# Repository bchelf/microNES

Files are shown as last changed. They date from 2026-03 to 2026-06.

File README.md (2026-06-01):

# microNES

<p align="center">
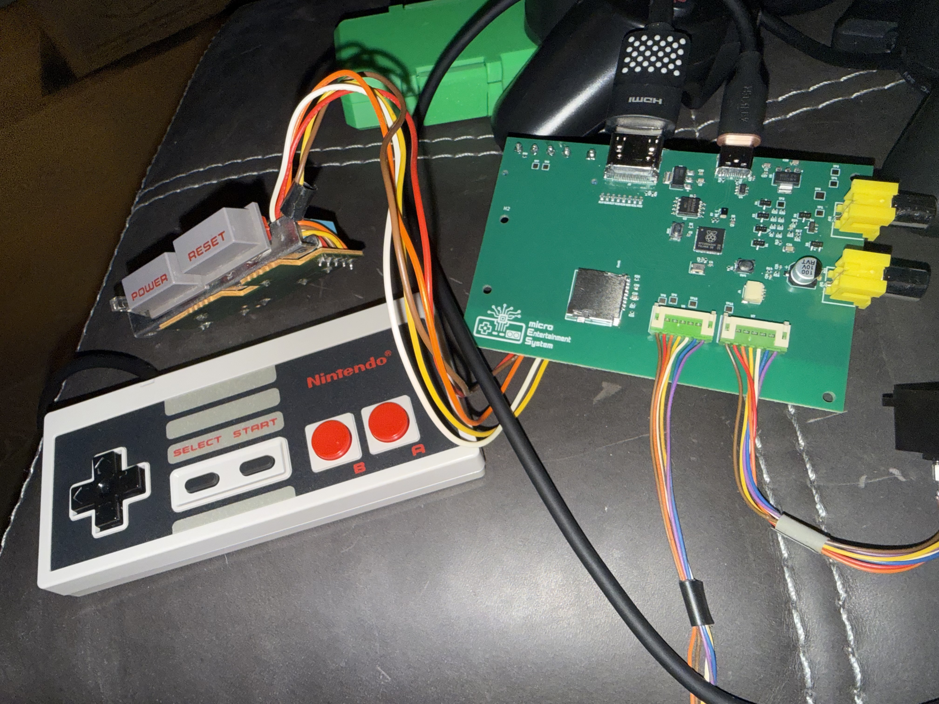
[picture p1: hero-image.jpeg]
microNES RP2350 NES emulator hardware
  
</p>

`microNES` is a small RP2350-based NES emulator project with custom hardware,
portable emulator code, and host-side development tools.

The repo now includes a complete KiCad implementation of an RP2350 console-style
board, plus firmware for composite video, HDMI output, SD-card ROM loading,
controller input, and audio. It also includes host tools for building, running,
capturing, and validating the same emulator core on a desktop.

ROM images are not included.

## What This Repo Does

- Runs NES ROMs through a shared C emulator core.
- Targets RP2350 / Raspberry Pi Pico 2-class hardware.
- Provides a fully functional KiCad PCB design under `hardware/microNES_pcb_v0.1`.
- Outputs analog composite video from the RP2350 using PIO/DMA timing.
- Outputs HDMI/DVI-style video using the RP2350 HSTX path.
- Loads ROMs at runtime from SD card, with an optional flash/XIP cache.
- Supports NES controller input.
- Produces audio through PWM on the Pico targets, with a MAX98357 I2S path for
  the TFT audio target.
- Builds host tools for smoke tests, SDL play, PNG frame dumps, WAV dumps, and
  ffmpeg video capture.
- Includes an ESP32-S3 frontend as a separate reference platform.
- Includes an Emscripten/WebAssembly target stub for browser experiments.

## Current Status

The project has moved beyond the original SMB1-only bring-up. The core still
prioritizes pragmatic compatibility over perfect NES accuracy, but the repo now
contains support for several common mapper families:

- NROM / mapper 0
- MMC1
- UxROM
- CNROM
- AxROM
- GxROM
- Color Dreams
- MMC2
- MMC3
- mapper 40

The hardware and firmware path is centered on the RP2350 board in
`hardware/microNES_pcb_v0.1`, with composite and HDMI firmware targets in
`src/pico`. The host path remains the fastest way to validate emulator behavior
before testing on hardware.

## Hardware

The KiCad project lives here:

```text
hardware/microNES_pcb_v0.1/
```

It includes:

- KiCad schematic and PCB files
- custom symbols and footprints
- RP2350 QFN footprint and 3D model support
- microSD slot support
- USB-C support
- NES controller connector footprint
- custom KiCad footprints for original Nintendo console parts
- composite output hardware
- production outputs, BOM, placement files, and Gerbers

The board is designed around harvested original NES console hardware for the
user-facing controls and controller interface. It uses the original Nintendo
power switch assembly and original NES controller input ports, with custom KiCad
footprints made specifically for those salvaged parts.

The older breadboard composite schematic is documented in `SCHEMATIC.md`. The
PCB target is selected in firmware with:

```sh
-DMICRONES_BOARD=v0_1
```

## Repo Layout

```text
src/common/      Portable emulator core, ROM menu, mappers, CPU, PPU, APU, input
src/host/        Desktop smoke runner, SDL runner, PNG/WAV/video tooling
src/pico/        RP2350 firmware, composite, HDMI, TFT, SD, flash cache, audio
src/esp32s3/     Separate ESP32-S3 frontend/reference implementation
src/web/         Emscripten/WebAssembly browser frontend
hardware/        KiCad PCB design, production files, Gerbers, BOMs
tests/           Emulator test ROMs and menu smoke tests
```

## Build

### Host

```sh
cmake -S . -B build-host -DMICRONES_PLATFORM=host
cmake --build build-host -j
```

This builds:

- `build-host/micrones_smoke`
- `build-host/micrones_menu_smoke`
- `build-host/micrones` when SDL3 is available

Run a ROM locally:

```sh
./build-host/micrones roms/smb1.nes
```

Run deterministic smoke validation:

```sh
./build-host/micrones_smoke roms/smb1.nes
```

Capture a frame or video:

```sh
./build-host/micrones_smoke roms/smb1.nes 6200000 /tmp/micrones_10s.png
./build-host/micrones_smoke roms/smb1.nes --steps 17670500 --video-out build-host/capture.mp4
```

### RP2350 / Pico

Configure the firmware for the emulator and the custom PCB:

```sh
cmake -S . -B build-pico \
  -DMICRONES_PLATFORM=pico \
  -DMICRONES_PICO_VIDEO_MODE=emulator \
  -DMICRONES_BOARD=v0_1 \
  -Dpicotool_DIR=/Users/bchelf/microNES/build/_deps/picotool
```

Build composite output:

```sh
cmake --build build-pico --target micrones_pico_analog -j
```

Build HDMI output:

```sh
cmake --build build-pico --target micrones_pico_hdmi -j
```

Other firmware targets:

```sh
cmake --build build-pico --target micrones_pico_tft -j
cmake --build build-pico --target micrones_pico_tft_max98357 -j
cmake --build build-pico --target micrones_pico_hdmi_test_pattern -j
```

The Pico firmware loads ROMs from SD at runtime. `MICRONES_PICO_ROM_PATH` is no
longer needed for normal Pico builds.

### Web

```sh
emcmake cmake -S . -B build-web -DMICRONES_PLATFORM=web
cmake --build build-web -j
```

The build copies `src/web/index.html` next to the generated JS/WASM output.

### ESP32-S3

```sh
cd src/esp32s3
. $IDF_PATH/export.sh
idf.py build
```

## Host Controls

For the SDL runner:

- Arrow keys or `WASD`: D-pad
- `L`: A
- `K`: B
- `Return`: Start
- `Tab` or right shift: Select

Useful runner options:

```sh
./build-host/micrones roms/smb1.nes --vsync
./build-host/micrones roms/smb1.nes --no-vsync --unthrottled
./build-host/micrones roms/smb1.nes --scale 5
./build-host/micrones roms/smb1.nes --dump-wav /tmp/gameplay.wav --dump-wav-seconds 2
```

## Known Limitations

`microNES` is still an emulator under active development, not a fully accurate
general-purpose NES implementation.

- PPU timing is practical rather than fully cycle-accurate.
- Sprite overflow and exact secondary OAM behavior are incomplete.
- APU fidelity is improved but still not perfect.
- Mapper support exists for several common boards, but compatibility is not
  expected to match mature NES emulators.
- Some RP2350 SD-to-flash-cache ROM load paths can still disturb video output
  and are an active debugging area.

## Development Notes

Keep platform boundaries clean:

- `src/common` should stay portable.
- Host-only SDL, PNG, WAV, and ffmpeg code belongs in `src/host`.
- Pico SDK, PIO, DMA, HSTX, SD, and flash code belongs in `src/pico`.
- ESP-IDF code belongs in `src/esp32s3`.

The recommended workflow is still host-first: validate behavior with
`micrones_smoke` and the SDL runner, then test the same core on RP2350 hardware.

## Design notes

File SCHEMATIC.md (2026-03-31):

# microNES Hardware Schematic

Raspberry Pi Pico 2 (RP2350) running SMB1 with color NTSC composite video output, PWM audio, and a hardware NES controller.

---

## GPIO Pin Assignments

| GPIO | Function | Direction |
|---|---|---|
| GP0  | Video DAC bit 0 (LSB) | Output |
| GP1  | Video DAC bit 1 | Output |
| GP2  | Video DAC bit 2 | Output |
| GP3  | Video DAC bit 3 (MSB) | Output |
| GP4  | Sync clamp MOSFET gate| Output |
| GP5  | NES CLOCK | Output |
| GP6  | NES LATCH | Output |
| GP7  | NES DATA | Input |
| GP9  | Audio PWM | Output |

---

## Composite Video Output

Color NTSC via a 4-bit binary-weighted resistor DAC on GP0–GP3. A MOSFET on GP4 clamps the output to GND during sync pulses for a clean sync tip.

```
GP0 ──[ 1000Ω ]──┐
GP1 ──[  485Ω ]──┤  (470Ω + 15Ω)
GP2 ──[  242Ω ]──┤  (220Ω + 22Ω)
GP3 ──[  120Ω ]──┴── Node A ──[ 75.5Ω series ]── RCA center pin

GP4 ──── MOSFET gate  (N-channel; drain → Node A, source → GND)

RCA shell ──── GND
```

The display provides a 75Ω termination load to ground. The 75.5Ω series resistor plus 75Ω load form a matched output impedance.

**DAC codes (analytically derived at 315 MHz / Node A with 75Ω load):**

| Code | Voltage at RCA | NTSC use |
|---|---|---|
|  0 | 0.000 V | Sync tip (GP4 clamp active) |
|  4 | 0.306 V | Blanking / back porch |
| 13 | 0.998 V | White luma |
| 15 | 1.151 V | Peak chroma headroom  |

Luma range: codes 4–13 (blank to white), scale factor 9 per step.
Chroma: ±2–3 DAC codes added/subtracted on active pixels, 13 hues × 4 subcarrier phases.

---

## Sync Clamp (GP4)

An N-channel MOSFET (e.g. 2N7002 or BSS138) pulls Node A to GND during sync intervals, ensuring the sync tip reaches true 0 V regardless of DAC resistor tolerances.

```
Node A ──── DRAIN
             │
            MOSFET (N-ch)
             │
GP4  ──── GATE
             │
            SOURCE ──── GND
```

GP4 is driven HIGH by the PIO DMA IRQ handler at the start of each sync interval and LOW ~1 µs later by Core 1.

---

## Audio Output

PWM audio on GP9, filtered to remove the 44 kHz carrier before the output jack.

```
GP9 ──[ 1kΩ ]──┬──[ 1kΩ ]──┬── 100µF (DC block) ──┬── audio jack tip
              [10nF]       [10nF]              [10kΩ to GND]
                │             │
               GND           GND
```

- PWM carrier: 44,103 Hz (315 MHz / 7143 — nearest integer to 44,100 Hz, 75 ppm error)
- Two-pole RC low-pass filter: R=1kΩ, C=10nF each pole, f_c ≈ 15.9 kHz
- 100µF DC-blocking cap + 10kΩ bleeder to GND on output
- BAT85 ESD diode pair recommended on the output jack
- Output: mono, line level (passive — may need amplification for speakers)

---

## NES Controller (Pico 2 / RP2350)

Original NES controller connected via its 7-pin cable. The controller contains a 4021 PISO (parallel-in, serial-out) shift register.

```
NES controller cable
  pin 1  VCC   ─── 3.3 V
  pin 2  CLOCK ─── GP5
  pin 3  LATCH ─── GP6
  pin 4  DATA  ─── GP7   (active-low output from controller)
  pin 5  N/C
  pin 6  N/C
  pin 7  GND   ─── GND
```

- DATA is active-low: the controller pulls it low for each pressed button.
- The Pico's internal pull-up on GP7 keeps the line high (no buttons pressed) when no controller is connected.
- No external resistors are needed on CLOCK, LATCH, or DATA.

---

## Full Wiring Summary

```
Pico 2 (RP2350)
┌──────────────────────────────────────────────────────┐
│ GP0 ──[ 1000Ω ]──┐                                   │
│ GP1 ──[  485Ω ]──┤                                   │
│ GP2 ──[  242Ω ]──┤                                   │
│ GP3 ──[  120Ω ]──┴── Node A ──[ 75.5Ω ]── RCA center│   RCA shell ── GND
│ GP4 ─────────────────── MOSFET gate (drain→Node A)   │
│                                                      │
│ GP5 ────────────────────────────────── NES CLOCK     │
│ GP6 ────────────────────────────────── NES LATCH     │
│ GP7 ────────────────────────────────── NES DATA      │
│                                                      │
│ GP9 ──[1kΩ]──[1kΩ]──[100µF]──[10kΩ↓]── audio jack  │
│         │      │                                     │
│        10nF   10nF                                   │
│         │      │                                     │
│ GND ────┴──────┴─────────────────────────────────────┘
│  │
│  └── NES GND, RCA shell, MOSFET source, jack GND
└─────────────────────────────────────────────────────────
```

---

## Notes

- Power the Pico via USB (5V). No additional power supply is needed.
- The Pico runs at exactly 315 MHz (PLL: VCO=1260 MHz, post_div1=2, post_div2=2) with VREG at 1.20V — within RP2350 spec.
- System clock is load-bearing: 315 MHz / 22 = 14.318182 MHz NTSC sample rate (colorburst × 4); 315 MHz / 7143 = 44,103 Hz audio PWM rate.
- All signal ground connections (RCA shell, NES controller, audio jack sleeve, MOSFET source) must share a common GND with the Pico.
- The composite output supports color. Chroma is generated by adding/subtracting DAC codes in sync with the 3.579545 MHz NTSC subcarrier (4 phases × 14.318 MHz ÷ 4).
- The NES controller is also supported on the ESP32-S3 target; see board.h for those pin assignments (GPIO 11/12/13).

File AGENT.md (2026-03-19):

# micrones Agent Notes

This file summarizes the current state of `micrones`, what has already been implemented and validated, what has been learned during debugging, and what remains.

## Project Intent

`micrones` is intentionally narrow:

- It is not a general NES emulator.
- It targets the original Super Mario Bros ROM.
- It only supports mapper 0 / NROM.
- It is being developed as a shared portable NES runtime plus thin host and Pico frontends.
- The long-term embedded target is RP2350 / Raspberry Pi Pico 2.

The current architecture is:

- `src/common/`
  - Portable shared emulator/runtime code.
  - No SDL, no Pico SDK, no host-only image/audio/window code.
- `src/host/`
  - Host-only tooling:
  - smoke validation runner
  - PNG export
  - ffmpeg video capture
  - SDL interactive runner
  - SDL audio playback
- `src/pico/`
  - Pico firmware and hardware-specific code.

## What Is Working

### Build / Targets

- Host smoke target builds and runs:
  - `build-host/micrones_smoke`
- Host SDL interactive runner builds and runs:
  - `build-host/micrones_run`
- Pico firmware builds and produces:
  - `build-pico/micrones.uf2`
  - `build-pico/micrones.elf`

### Core Emulator

- iNES ROM parsing works.
- Mapper 0 / NROM-only support works.
- CPU execution is deterministic for SMB1.
- Missing official CPU opcodes needed by SMB1 have already been implemented.
- No illegal opcodes have been required by SMB1 so far.
- Deterministic host validation has repeatedly passed.

### PPU / Video

- Background rendering exists and produces a visible `256x240` framebuffer.
- Minimal sprite composition exists.
- Sprite 0 hit is implemented from real OAM/background overlap.
- SMB1 gets past the early and later sprite-0-hit wait loops.
- The later sprite-0-hit failure was traced to background address derivation and fixed with a more honest latched `v/t/x/w`-style model.
- A later visual split bug near the HUD/title-card boundary was traced to deferred whole-scanline rendering using stale scanline-start scroll state when SMB updated `PPUSCROLL` on visible scanline 32.
- That split bug was fixed by refreshing the deferred scanline render latch when visible writes hit scroll-affecting PPU registers.

### Host Tooling

- PNG export works from the host runner.
- ffmpeg video capture works by piping raw grayscale frames into ffmpeg.
- SDL interactive window works.
- Keyboard input mapping works for SMB1 gameplay.
- Host-side approximate color mapping exists for SDL display.
- Host-side frame pacing infrastructure exists.

### Audio

- Shared-core PCM sample pipeline exists in `src/common`.
- Host-side SDL audio playback works.
- SMB1 audio is audible and recognizable.
- Audio is still incomplete and simplified.

## Current Architecture Details

### Shared Core

Key portable areas include:

- CPU
- PPU
- APU
- cartridge/NROM
- input/controller state
- framebuffer and scanline types
- frame pacing abstraction

Important design rule:

- Keep emulator logic portable.
- Do not add host-only or Pico-only dependencies to `src/common/`.

### Host Side

Current host capabilities:

- smoke validation with deterministic reporting
- frame hashing and state hashing
- sprite-0 diagnostics
- PNG export
- ffmpeg video capture
- SDL interactive window
- SDL keyboard controller input
- SDL audio playback

### Pico Side

Current Pico scope:

- buildable firmware
- earlier composite bring-up code still exists
- Pico-specific timing shim exists for future shared pacing integration

Do not assume the Pico runtime is yet using the full host-side emulator/display/audio path.

## Important Findings So Far

### 1. SMB1 CPU Execution Was Not the Main Blocker

Earlier debugging showed SMB1 could run millions of instructions deterministically. Once the missing official opcodes needed by SMB1 were implemented, the next blockers were PPU-side, not CPU decode.

### 2. The First Major Gameplay Stall Was Sprite-0-Hit Related

SMB1 stalled in the loop at:

- `LDA $2002`
- `AND #$40`
- `BEQ ...`

This was because `PPUSTATUS` bit 6 was never being raised. The minimal viable sprite-0-hit path fixed that.

### 3. The Later Gameplay Stall Was Also Not a Sprite-OAM Problem

Forensic work showed that later in gameplay:

- sprite 0 OAM remained plausible
- sprite 0 still had nonzero pixels
- sprite 0 still appeared in first-8 scanline selection
- the actual failure was that background under sprite 0 became transparent in the current model

This pointed to background/scroll/address derivation, not sprite corruption.

### 4. A More Honest Latched Scroll/Address Model Was Required

The simplified global scroll model was not enough. Moving to a more honest `PPUCTRL` / `PPUSCROLL` / `PPUADDR`-driven latched address model was required to keep later sprite-0 hit behavior working.

### 5. The HUD / Title-Card Visual Artifact Was a Same-Scanline Split Bug

The artifact became visually obvious around 8-10 seconds into gameplay.

Observed symptom:

- a line at the top of the title card persisted instead of scrolling with the card
- this was visible in PNG/video captures, so not an SDL presentation issue

What we learned:

- the bad row was scanline `32`
- SMB writes `PPUSCROLL` during visible scanline `32`
- the renderer defers whole-scanline drawing until end-of-line
- the scanline renderer had been using stale line-start render state for that row

Minimal fix:

- when visible writes hit `PPUCTRL`, `PPUSCROLL`, or `PPUADDR`, refresh the deferred scanline render latch for that same line

This preserved the scanline-based renderer without a broad PPU rewrite.

## Determinism / Validation Status

Validated repeatedly:

- host smoke determinism passes
- frame hashes are stable under repeat runs
- sprite-0 hit behavior is deterministic
- host and Pico builds both succeed after recent changes

Useful smoke commands:

```sh
cd /Users/bchelf/microNES
cmake --build build-host -j
./build-host/micrones_smoke roms/smb1.nes
```

Frame dump examples:

```sh
./build-host/micrones_smoke roms/smb1.nes 5000000 /tmp/micrones_8s.png
./build-host/micrones_smoke roms/smb1.nes 6200000 /tmp/micrones_10s.png
```

Video capture example:

```sh
./build-host/micrones_smoke roms/smb1.nes --steps 17670500 --video-out build-host/smb_30s.mp4
```

SDL runner:

```sh
./build-host/micrones_run roms/smb1.nes
```

## Current Audio Status

Audio is working end-to-end, but it is still incomplete.

What is true right now:

- audible SMB1 audio exists
- it is recognizable and in sync
- it is not badly delayed or grossly distorted

Known limitations:

- bass is still weaker than it should be
- some sound effects still sound abbreviated or clipped at the tail
- APU behavior is still approximate
- noise/DMC/precise envelope/frame-counter behavior are not yet complete enough for faithful SMB audio

Conclusion:

- the SDL host audio backend is probably not the main problem now
- the remaining work is primarily in `src/common/apu.*`

## Current Rendering Status

What works:

- background rendering is solid enough for SMB1 progression and inspection
- sprite composition is present and sufficient for recognizable gameplay
- sprite-0 hit works in early and later gameplay
- the major late split bug at the HUD/title-card boundary has been fixed narrowly

What is still simplified:

- no cycle-accurate PPU fetch pipeline
- no exact secondary OAM behavior
- no sprite overflow behavior
- no full palette-accurate NES color in the core
- host color display is still an approximation layered on top of the debug-oriented framebuffer

## Current Host SDL Status

Interactive runner status:

- window rendering works
- keyboard input works
- gameplay works
- grayscale upload bug was fixed by using the correct SDL pixel format for byte-wise RGBA data
- approximate host-only color mapping exists
- frame pacing exists but can still look choppy or tear depending on mode

Likely causes of choppiness/tearing already identified:

- pacer-driven presentation with vsync disabled
- host scheduling jitter
- refresh mismatch between NES cadence and actual display

Practical modes:

- live play: prefer `--vsync`
- benchmarking/perf: prefer `--no-vsync --unthrottled`

## What Remains

### APU

Highest-value remaining audio work:

- improve frame sequencer timing
- improve envelope behavior
- improve length counter behavior
- improve triangle sustain / presence
- improve pulse/noise completeness

### PPU

Still intentionally incomplete:

- no full cycle-accurate PPU
- no exact per-dot reload/fetch behavior
- no sprite overflow emulation
- no exact secondary OAM behavior
- no exact final NES palette behavior in the core

### Pico Runtime Integration

Still to do later:

- connect the shared emulator core to a Pico-ready video path
- connect the shared PCM sample pipeline to a Pico audio backend
- integrate the shared frame pacer into the eventual Pico runtime loop
- performance work for RP2350

### General Project Direction

The next work should stay disciplined:

- avoid broad emulator-generalization
- continue prioritizing SMB1-specific correctness
- keep portability boundaries intact

## Guidelines for Future Changes

- Prefer narrow fixes over broad rewrites.
- Do not add host-only code to `src/common/`.
- Do not add Pico SDK dependencies to the shared core.
- Keep deterministic smoke validation healthy after every meaningful renderer/APU change.
- When debugging rendering:
  - capture PNGs/videos from host tooling
  - compare frame windows numerically when possible
  - instrument exact PPU register writes before assuming generic tile-fetch corruption
- When debugging gameplay stalls:
  - first determine whether CPU, PPU, NMI, frame hashes, and sprite-0 hit are still advancing
  - do not guess broadly without evidence

## Current Repo-Specific Commands

Build host:

```sh
cd /Users/bchelf/microNES
cmake -S . -B build-host -DMICRONES_PLATFORM=host
cmake --build build-host -j
```

Build Pico:

```sh
cd /Users/bchelf/microNES
source ~/.zshrc
cmake -S . -B build-pico -DMICRONES_PLATFORM=pico -Dpicotool_DIR=/Users/bchelf/microNES/build/_deps/picotool
cmake --build build-pico -j
```

Run SDL:

```sh
./build-host/micrones_run roms/smb1.nes
```

Run smoke:

```sh
./build-host/micrones_smoke roms/smb1.nes
```

## Current Bottom Line

`micrones` now has:

- a serious shared SMB1/NROM runtime
- deterministic host validation
- working framebuffer generation
- working sprite-0 hit
- working host PNG/video capture
- working host SDL interaction
- working first-pass audio pipeline

The main remaining technical debt is:

- APU completeness
- deeper PPU accuracy where SMB later requires it
- eventual Pico-side integration/performance work

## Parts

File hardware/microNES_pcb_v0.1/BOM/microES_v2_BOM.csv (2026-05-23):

Comment | Designator | Footprint | JLCPCB Part #
AV-5 | AV1,AV2 | microNES_footprints:CONN-TH_AV-5 | C18080
10uF | C1,C5,C19,C26,C29 | Capacitor_SMD:C_0603_1608Metric | C19702
100nF | C2,C8,C11,C12,C13,C14,C15,C16,C17,C18,C20,C27,C28,C30 | Capacitor_SMD:C_0402_1005Metric | C307331
15pF | C3,C4 | Capacitor_SMD:C_0402_1005Metric | C1548
4.7uF | C6,C7,C9,C10 | Capacitor_SMD:C_0402_1005Metric | C23733
100nF | C21 | Capacitor_SMD:C_0805_2012Metric | C49678
10nF | C22,C24,C25 | Capacitor_SMD:C_0402_1005Metric | C15195
100uF | C23 | Capacitor_SMD:CP_Elec_6.3x5.4 | C29179
TF PUSH | Card1 | microNES_footprints:TF-SMD_TF-PUSH | C393941
BAT54S | D1,D2,D3,D4,D5,D6 | Package_TO_SOT_SMD:SOT-23 | C47546
USB_C_Receptacle_USB2.0_16P | J1 | microNES_footprints:USB-C_SMD-TYPE-C-31-M-12_1 | C165948
HDMI_E | J3 | Connector_Video:HDMI_A_Molex_208658-1001_Horizontal | C2962407
SM03B-SRSS-TB | J4 | Connector_JST:JST_SH_SM03B-SRSS-TB_1x03-1MP_P1.00mm_Horizontal | C160403
3.3uH | L1 | microNES_footprints:IND-SMD_L2.0-W1.6_AOTA-B201610S3R3-101-T | C42411119
2N7002 | Q1 | Package_TO_SOT_SMD:SOT-23 | C8545
1k | R2,R3,R4,R6,R14,R16 | Resistor_SMD:R_0402_1005Metric | C11702
33 | R5 | Resistor_SMD:R_0402_1005Metric | C25105
27 | R7,R8 | Resistor_SMD:R_0402_1005Metric | C25100
270 | R10,R26,R27,R28,R29,R30,R31,R32 | Resistor_SMD:R_0603_1608Metric | C22966
5.1k | R11,R12 | Resistor_SMD:R_0402_1005Metric | C25905
330 | R13,R40 | Resistor_SMD:R_0402_1005Metric | C25104
10k | R15,R21,R33,R35,R36,R37 | Resistor_SMD:R_0402_1005Metric | C2765610
7.5 | R17 | Resistor_SMD:R_0402_1005Metric | C47764
68 | R18 | Resistor_SMD:R_0402_1005Metric | C25131
15 | R19 | Resistor_SMD:R_0402_1005Metric | C25083
470 | R20 | Resistor_SMD:R_0402_1005Metric | C25117
22 | R22 | Resistor_SMD:R_0402_1005Metric | C25092
220 | R23 | Resistor_SMD:R_0402_1005Metric | C25091
100 | R24 | Resistor_SMD:R_0402_1005Metric | C2784782
120 | R25 | Resistor_SMD:R_0402_1005Metric | C25079
20k | R34 | Resistor_SMD:R_0402_1005Metric | C25765
0 | R38,R39 | Resistor_SMD:R_0402_1005Metric | C17168
PTS810SJM250SMTRLFS | SW3,SW4 | microNES_footprints:KEY-SMD_4P-L4.2-W3.2-P2.20-LS4.6 | C116501
RP2350_60QFN | U1 | microNES_footprints:RP2350-QFN-60-1EP_7x7_P0.4mm_EP3.4x3.4mm_ThermalVias | C42411118
AMS1117-3.3 | U2,U5 | Package_TO_SOT_SMD:SOT-223-3_TabPin2 | C6186
W25Q128JVS | U3 | Package_SO:SOIC-8_5.3x5.3mm_P1.27mm | C97521
 | U4 | Package_TO_SOT_SMD:SOT-23-6 | C7519
ABM8-272-T3 | Y1 | Crystal:Crystal_SMD_3225-4Pin_3.2x2.5mm | C20625731

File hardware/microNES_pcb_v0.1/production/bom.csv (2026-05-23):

Designator | Footprint | Quantity | Value | LCSC Part #
AV1, AV2 | CONN-TH_AV-5 | 2 | AV-5 | C18080
C1 | 0603 | 1 | 10uF
C10, C6, C7, C9 | 0402 | 4 | 4.7uF | C23733
C11, C12, C13, C14, C15, C16, C17, C18, C2, C20, C27, C28, C30, C8 | 0402 | 14 | 100nF | C307331
C19, C26, C29, C5 | 0603 | 4 | 10uF | C19702
C21 | 0805 | 1 | 100nF | C49678
C22, C24, C25 | 0402 | 3 | 10nF | C15195
C23 | CP_Elec_6.3x5.4 | 1 | 100uF | C29179
C3, C4 | 0402 | 2 | 15pF | C1548
CARD1 | TF-SMD_TF-PUSH | 1 | TF PUSH | C393941
D1, D2, D3, D4, D5, D6 | SOT-23 | 6 | BAT54S | C47546
H1, H2, H3, H4 | MountingHole_2.7mm_M2.5 | 4 | MountingHole
J1 | USB-C_SMD-TYPE-C-31-M-12_1 | 1 | USB_C_Receptacle_USB2.0_16P | C165948
J3 | HDMI_A_Molex_208658-1001_Horizontal | 1 | HDMI_E | C2962407
J4 | JST_SH_SM03B-SRSS-TB_1x03-1MP_P1.00mm_Horizontal | 1 | SM03B-SRSS-TB | C160403
L1 | IND-SMD_L2.0-W1.6_AOTA-B201610S3R3-101-T | 1 | 3.3uH | C42411119
Q1 | SOT-23 | 1 | 2N7002 | C8545
R10, R26, R27, R28, R29, R30, R31, R32 | 0603 | 8 | 270 | C22966
R11, R12 | 0402 | 2 | 5.1k | C25905
R13, R40 | 0402 | 2 | 330 | C25104
R14, R16, R3 | 0402 | 3 | 1k | C2784783
R15, R21, R33, R35, R36, R37 | 0402 | 6 | 10k | C2765610
R17 | 0402 | 1 | 7.5 | C47764
R18 | 0402 | 1 | 68 | C25131
R19 | 0402 | 1 | 15 | C25083
R2, R4, R6 | 0402 | 3 | 1k | C11702
R20 | 0402 | 1 | 470 | C25117
R22 | 0402 | 1 | 22 | C25092
R23 | 0402 | 1 | 220 | C25091
R24 | 0402 | 1 | 100 | C2784782
R25 | 0402 | 1 | 120 | C25079
R34 | 0402 | 1 | 20k | C25765
R38, R39 | 0402 | 2 | 0 | C17168
R5 | 0402 | 1 | 33 | C25105
R7 | 0402 | 1 | 27 | C25100
R8 | 0402 | 1 | 27 | C25100
SW3, SW4 | KEY-SMD_4P-L4.2-W3.2-P2.20-LS4.6 | 2 | PTS810SJM250SMTRLFS | C116501
TP1 | TestPoint_Pad_1.5x1.5mm | 1 | TestPoint
TP10, TP11, TP2, TP3, TP4, TP6, TP7, TP8, TP9 | TestPoint_Pad_1.5x1.5mm | 9 | ~
TP5 | TestPoint_Pad_2.0x2.0mm | 1 | TestPoint
U1 | RP2350-QFN-60-1EP_7x7_P0.4mm_EP3.4x3.4mm_ThermalVias | 1 | RP2350_60QFN | C42411118
U2, U5 | SOT-223-3_TabPin2 | 2 | AMS1117-3.3 | C6186
U3 | SOIC-8_5.3x5.3mm_P1.27mm | 1 | W25Q128JVS | C97521
U4 | SOT-23-6 | 1 | ~ | C7519
U6, U7 | NES_1x7_CustomPitch | 2 | ~
U8 | NES_Power_Reset_LED_5pin | 1 | ~
Y1 | Crystal_SMD_3225-4Pin_3.2x2.5mm | 1 | ABM8-272-T3 | C20625731

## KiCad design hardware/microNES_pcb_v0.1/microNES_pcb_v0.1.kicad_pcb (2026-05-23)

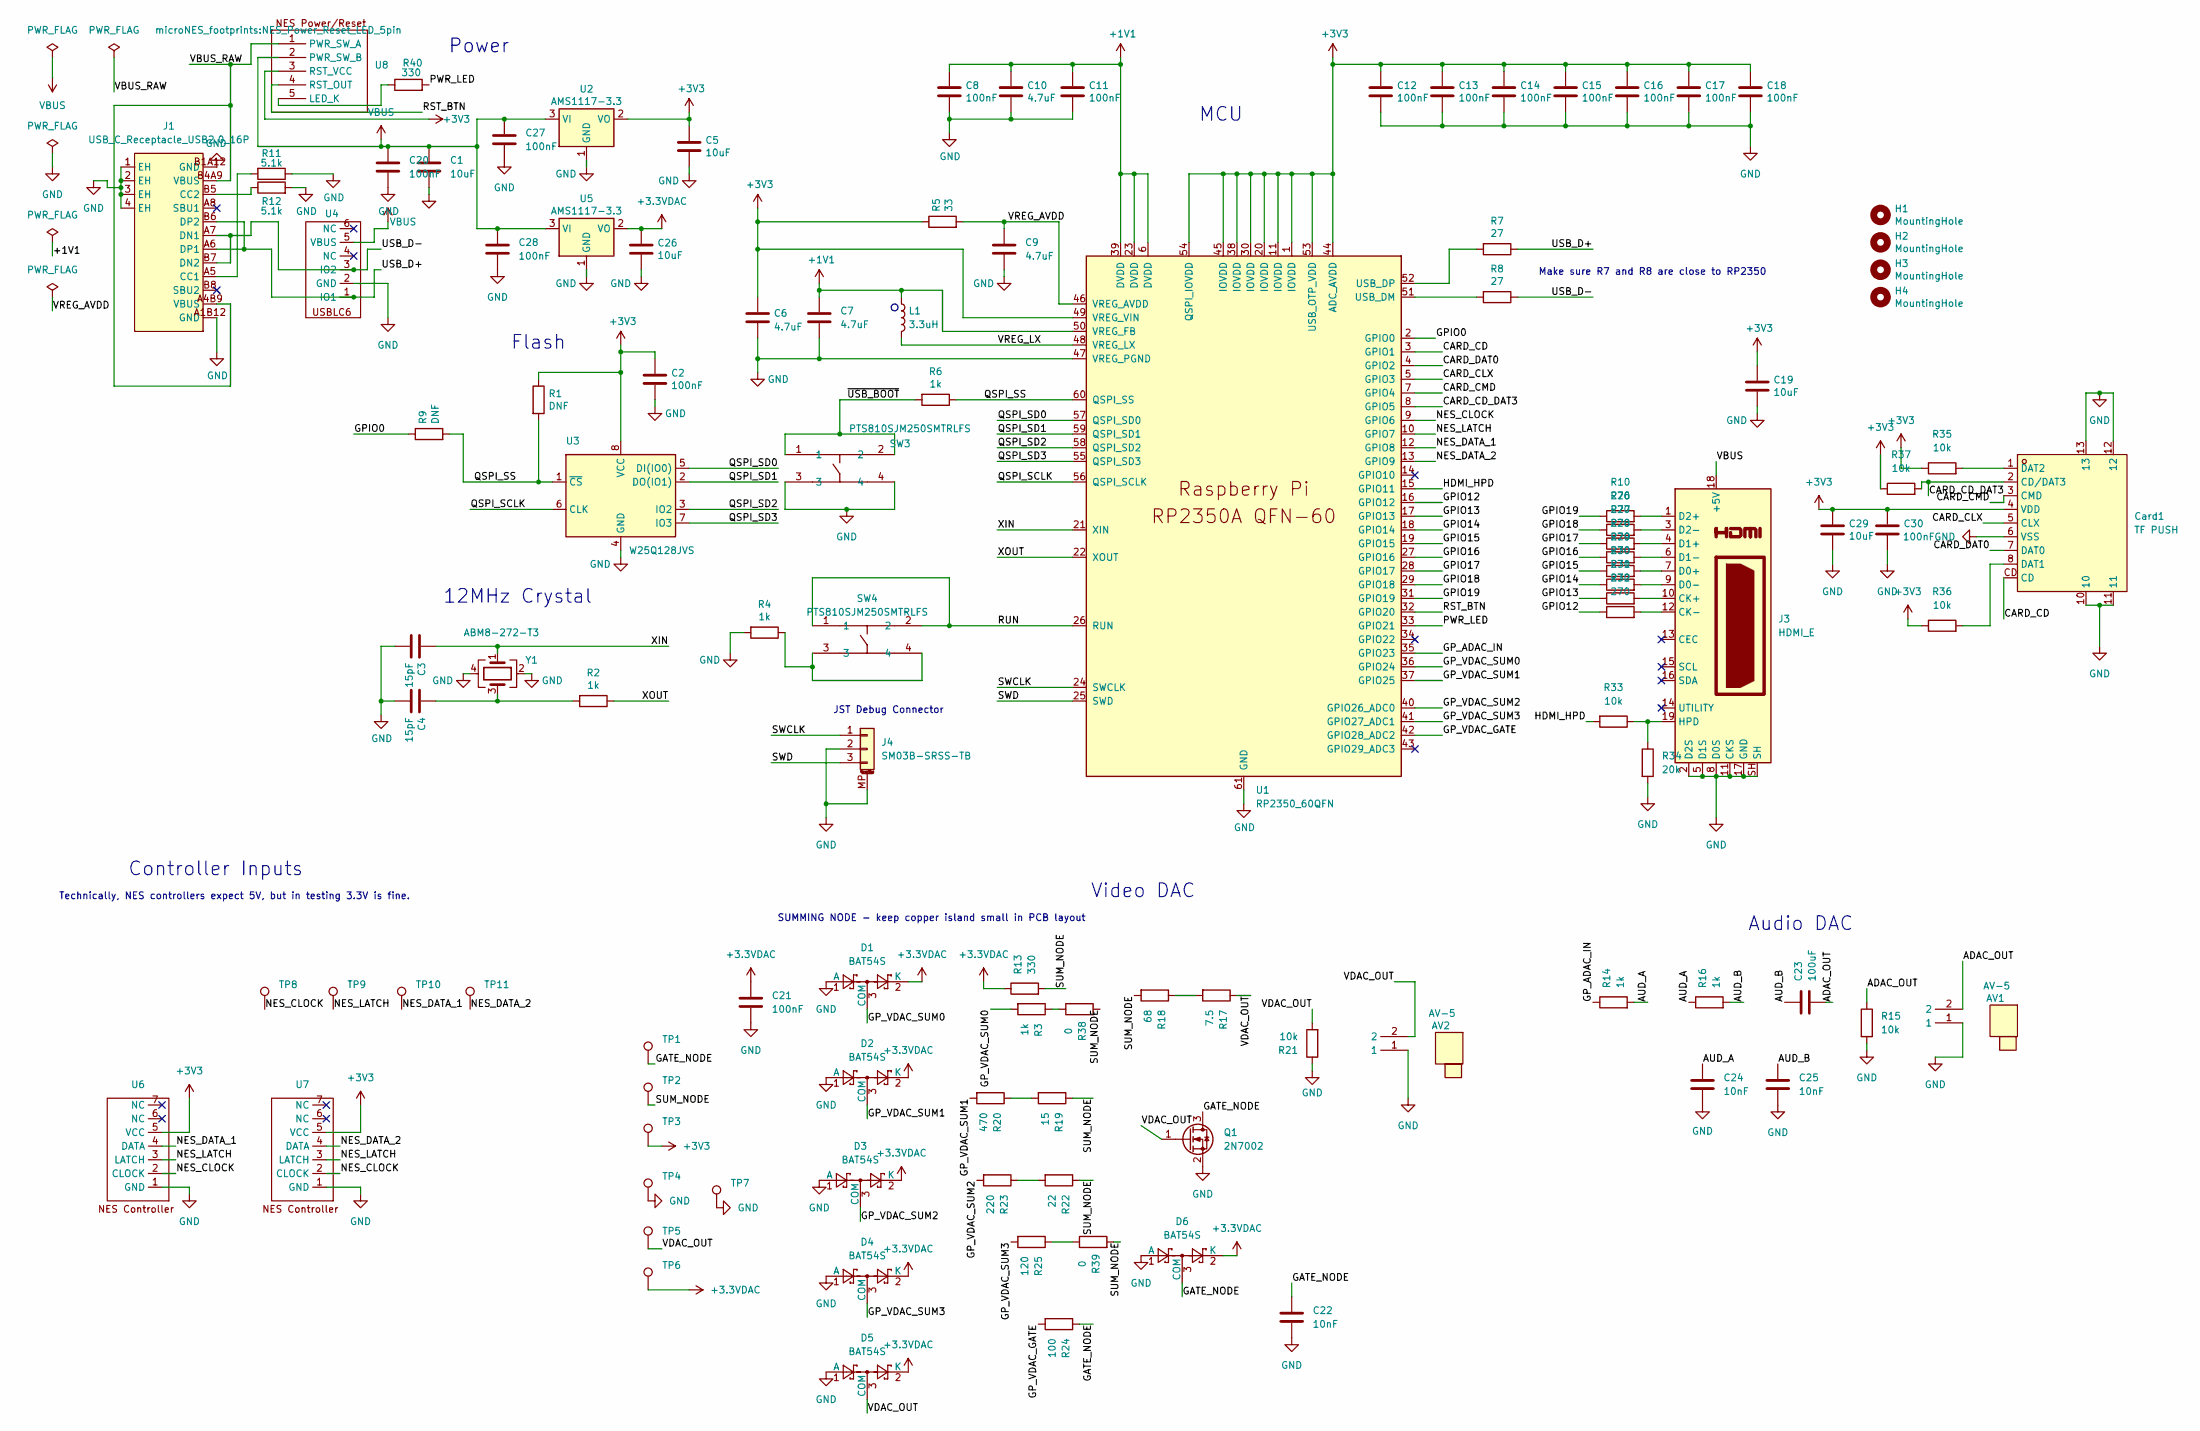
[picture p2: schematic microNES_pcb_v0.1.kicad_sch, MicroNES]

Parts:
AV1: AV-5; CONN-TH_AV-5; MPN AV-5; LCSC C18080
AV2: AV-5; CONN-TH_AV-5; MPN AV-5; LCSC Part C18080
C1: 10uF; C_0603_1608Metric
C2, C8, C11, C12, C13, C14, C15, C16, C17, C18, C20, C27, C28, C30: 100nF; C_0402_1005Metric; LCSC C307331
C3, C4: 15pF; C_0402_1005Metric; LCSC C1548
C5, C19, C26, C29: 10uF; C_0603_1608Metric; LCSC C19702
C6, C7, C9, C10: 4.7uF; C_0402_1005Metric; LCSC C23733
C21: 100nF; C_0805_2012Metric; LCSC C49678
C22, C24, C25: 10nF; C_0402_1005Metric; LCSC C15195
C23: 100uF; CP_Elec_6.3x5.4; LCSC C29179
Card1: TF PUSH; TF-SMD_TF-PUSH; MPN TF PUSH; LCSC C393941
D1, D2, D3, D4, D5, D6: BAT54S; SOT-23; LCSC C47546
H1, H2, H3, H4: MountingHole; MountingHole_2.7mm_M2.5
J1: USB_C_Receptacle_USB2.0_16P; USB-C_SMD-TYPE-C-31-M-12_1; LCSC C165948
J3: HDMI_E; HDMI_A_Molex_208658-1001_Horizontal; LCSC C2962407
J4: SM03B-SRSS-TB; JST_SH_SM03B-SRSS-TB_1x03-1MP_P1.00mm_Horizontal; LCSC C160403
L1: 3.3uH; IND-SMD_L2.0-W1.6_AOTA-B201610S3R3-101-T; LCSC C42411119
Q1: 2N7002; SOT-23; LCSC C8545
R1, R9: DNF; R_0402_1005Metric
R2, R4, R6: 1k; R_0402_1005Metric; LCSC C11702
R3, R14, R16: 1k; R_0402_1005Metric; LCSC C2784783
R5: 33; R_0402_1005Metric; LCSC C25105
R7, R8: 27; R_0402_1005Metric; LCSC C25100
R10, R26, R27, R28, R29, R30, R31, R32: 270; R_0603_1608Metric; LCSC C22966
R11, R12: 5.1k; R_0402_1005Metric; LCSC C25905
R13, R40: 330; R_0402_1005Metric; LCSC C25104
R15, R21, R33, R35, R36, R37: 10k; R_0402_1005Metric; LCSC C2765610
R17: 7.5; R_0402_1005Metric; LCSC C47764
R18: 68; R_0402_1005Metric; LCSC C25131
R19: 15; R_0402_1005Metric; LCSC C25083
R20: 470; R_0402_1005Metric; LCSC C25117
R22: 22; R_0402_1005Metric; LCSC C25092
R23: 220; R_0402_1005Metric; LCSC C25091
R24: 100; R_0402_1005Metric; LCSC C25076
R25: 120; R_0402_1005Metric; LCSC C25079
R34: 20k; R_0402_1005Metric; LCSC C25765
R38, R39: 0; R_0402_1005Metric; LCSC C17168
SW3: PTS810SJM250SMTRLFS; KEY-SMD_4P-L4.2-W3.2-P2.20-LS4.6; MPN PTS810SJM250SMTRLFS; LCSC C116501
SW4: PTS810SJM250SMTRLFS; KEY-SMD_4P-L4.2-W3.2-P2.20-LS4.6; MPN PTS810SJM250SMTRLFS; LCSC Part C116501
TP1: TestPoint; TestPoint_Pad_1.5x1.5mm
TP2, TP3, TP4, TP6, TP7, TP8, TP9, TP10, TP11: TestPoint_Pad_1.5x1.5mm
TP5: TestPoint; TestPoint_Pad_2.0x2.0mm
U1: RP2350_60QFN; RP2350-QFN-60-1EP_7x7_P0.4mm_EP3.4x3.4mm_ThermalVias; LCSC C42411118
U2, U5: AMS1117-3.3; SOT-223-3_TabPin2; LCSC C6186
U3: W25Q128JVS; SOIC-8_5.3x5.3mm_P1.27mm; LCSC C97521
U4: SOT-23-6; LCSC C7519
U6, U7: NES_1x7_CustomPitch
U8: NES_Power_Reset_LED_5pin
Y1: ABM8-272-T3; Crystal_SMD_3225-4Pin_3.2x2.5mm; LCSC C20625731

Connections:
+1V1: C7.1, C8.1, C10.1, C11.1, L1.1, U1.6 (DVDD), U1.23 (DVDD), U1.39 (DVDD), U1.50 (VREG_FB)
+3.3VDAC: C21.1, C26.1, D1.2 (K), D2.2 (K), D3.2 (K), D4.2 (K), D5.2 (K), D6.2 (K), R13.1, TP6.1 (1_1), U5.2 (VO)
+3V3: C2.1, C5.1, C6.1, C12.1, C13.1, C14.1, C15.1, C16.1, C17.1, C18.1, C19.1, C29.1, C30.1, Card1.4 (VDD), R1.1, R5.1, R35.1, R36.1, R37.1, TP3.1 (1_1), U1.1 (IOVDD), U1.11 (IOVDD), U1.20 (IOVDD), U1.30 (IOVDD), U1.38 (IOVDD), U1.44 (ADC_AVDD), U1.45 (IOVDD), U1.49 (VREG_VIN), U1.53 (USB_OTP_VDD), U1.54 (QSPI_IOVDD), U2.2 (VO), U3.8 (VCC), U6.5 (VCC), U7.5 (VCC), U8.3 (RST_VCC)
/ADAC_OUT: AV1.2, C23.2, R15.1
/AUD_A: C24.1, R14.2, R16.1
/AUD_B: C23.1, C25.1, R16.2
/CARD_CD: Card1.CD, U1.3 (GPIO1)
/CARD_CD_DAT3: Card1.2 (CD/DAT3), R37.2, U1.8 (GPIO5)
/CARD_CLX: Card1.5 (CLX), U1.5 (GPIO3)
/CARD_CMD: Card1.3 (CMD), U1.7 (GPIO4)
/CARD_DAT0: Card1.7 (DAT0), U1.4 (GPIO2)
/GATE_NODE: C22.1, D6.3 (COM), Q1.3 (D), R24.1, TP1.1 (1_1)
/GPIO0: R9.1, U1.2 (GPIO0)
/GPIO12: R32.1, U1.16 (GPIO12)
/GPIO13: R31.1, U1.17 (GPIO13)
/GPIO14: R30.1, U1.18 (GPIO14)
/GPIO15: R29.1, U1.19 (GPIO15)
/GPIO16: R28.1, U1.27 (GPIO16)
/GPIO17: R27.1, U1.28 (GPIO17)
/GPIO18: R26.1, U1.29 (GPIO18)
/GPIO19: R10.1, U1.31 (GPIO19)
/GP_ADAC_IN: R14.1, U1.35 (GPIO23)
/GP_VDAC_GATE: R24.2, U1.42 (GPIO28_ADC2)
/GP_VDAC_SUM0: D1.3 (COM), R3.2, U1.36 (GPIO24)
/GP_VDAC_SUM1: D2.3 (COM), R20.2, U1.37 (GPIO25)
/GP_VDAC_SUM2: D3.3 (COM), R23.2, U1.40 (GPIO26_ADC0)
/GP_VDAC_SUM3: D4.3 (COM), R25.2, U1.41 (GPIO27_ADC1)
/HDMI_HPD: R33.2, U1.15 (GPIO11)
/NES_CLOCK: TP8.1 (1_1), U1.9 (GPIO6), U6.2 (CLOCK), U7.2 (CLOCK)
/NES_DATA_1: TP10.1 (1_1), U1.12 (GPIO8), U6.4 (DATA)
/NES_DATA_2: TP11.1 (1_1), U1.13 (GPIO9), U7.4 (DATA)
/NES_LATCH: TP9.1 (1_1), U1.10 (GPIO7), U6.3 (LATCH), U7.3 (LATCH)
/PWR_LED: R40.2, U1.33 (GPIO21)
/QSPI_SCLK: U1.56 (QSPI_SCLK), U3.6 (CLK)
/QSPI_SD0: U1.57 (QSPI_SD0), U3.5 (DI(IO0))
/QSPI_SD1: U1.59 (QSPI_SD1), U3.2 (DO(IO1))
/QSPI_SD2: U1.58 (QSPI_SD2), U3.3 (IO2)
/QSPI_SD3: U1.55 (QSPI_SD3), U3.7 (IO3)
/QSPI_SS: R1.2, R6.1, R9.2, U1.60 (QSPI_SS), U3.1 (~CS)
/RST_BTN: U1.32 (GPIO20), U8.4 (RST_OUT)
/RUN: SW4.1, SW4.2, U1.26 (RUN)
/SUM_NODE: R13.2, R18.2, R19.1, R22.1, R38.2, R39.2, TP2.1 (1_1)
/SWCLK: J4.1, U1.24 (SWCLK)
/SWD: J4.3, U1.25 (SWD)
/USB_D+: J1.A6 (DP1), J1.B6 (DP2), R7.1, U4.1 (IO1)
/USB_D-: J1.A7 (DN1), J1.B7 (DN2), R8.1, U4.3 (IO2)
/VBUS_RAW: J1.A4B9 (VBUS), J1.B4A9 (VBUS), U8.1 (PWR_SW_A)
/VDAC_OUT: AV2.2, D5.3 (COM), Q1.1 (G), R17.1, R21.2, TP5.1 (1_1)
/VREG_AVDD: C9.1, R5.2, U1.46 (VREG_AVDD)
/VREG_LX: L1.2, U1.48 (VREG_LX)
/XIN: C3.1, U1.21 (XIN), Y1.1
/XOUT: R2.1, U1.22 (XOUT)
/~USB_BOOT: R6.2, SW3.1, SW3.2
GND: AV1.1, AV2.1, C1.1, C2.2, C3.2, C4.2, C5.2, C6.2, C7.2, C8.2, C9.2, C10.2, C11.2, C12.2, C13.2, C14.2, C15.2, C16.2, C17.2, C18.2, C19.2, C20.1, C21.2, C22.2, C24.2, C25.2, C26.2, C27.1, C28.1, C29.2, C30.2, Card1.6 (VSS), Card1.10, Card1.11, Card1.12, Card1.13, D1.1 (A), D2.1 (A), D3.1 (A), D4.1 (A), D5.1 (A), D6.1 (A), J1.1 (EH), J1.2 (EH), J1.3 (EH), J1.4 (EH), J1.A1B12 (GND), J1.B1A12 (GND), J3.2 (D2S), J3.5 (D1S), J3.8 (D0S), J3.11 (CKS), J3.17 (GND), J3.SH, J4.2, J4.MP (MountPin), Q1.2 (S), R4.2, R11.1, R12.2, R15.2, R21.1, R34.2, SW3.3, SW3.4, TP4.1 (1_1), TP7.1 (1_1), U1.47 (VREG_PGND), U1.61 (GND), U2.1 (GND), U3.4 (GND), U4.2 (GND), U5.1 (GND), U6.1 (GND), U7.1 (GND), Y1.2, Y1.4
unnamed: C4.1, R2.2, Y1.3
unnamed: Card1.8 (DAT1), R36.2
unnamed: Card1.1 (DAT2), R35.2
unnamed: J1.A5 (CC1), R11.2
unnamed: J1.B5 (CC2), R12.1
unnamed: J3.10 (CK+), R31.2
unnamed: J3.12 (CK-), R32.2
unnamed: J3.7 (D0+), R29.2
unnamed: J3.9 (D0-), R30.2
unnamed: J3.4 (D1+), R27.2
unnamed: J3.6 (D1-), R28.2
unnamed: J3.1 (D2+), R10.2
unnamed: J3.3 (D2-), R26.2
unnamed: J3.19 (HPD), R33.1, R34.1
unnamed: R3.1, R38.1
unnamed: R4.1, SW4.3, SW4.4
unnamed: R17.2, R18.1
unnamed: R19.2, R20.1
unnamed: R22.2, R23.1
unnamed: R25.1, R39.1
unnamed: R8.2, U1.51 (USB_DM)
unnamed: R7.2, U1.52 (USB_DP)
unnamed: R40.1, U8.5 (LED_K)
VBUS: C1.2, C20.2, C27.2, C28.2, J3.18 (+5V), U2.3 (VI), U4.5 (VBUS), U5.3 (VI), U8.2 (PWR_SW_B)

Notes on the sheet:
Technically, NES controllers expect 5V, but in testing 3.3V is fine.
Flash
MCU
Video DAC
Controller Inputs
12MHz Crystal
Make sure R7 and R8 are close to RP2350
JST Debug Connector
Audio DAC
SUMMING NODE - keep copper island small in PCB layout
Power

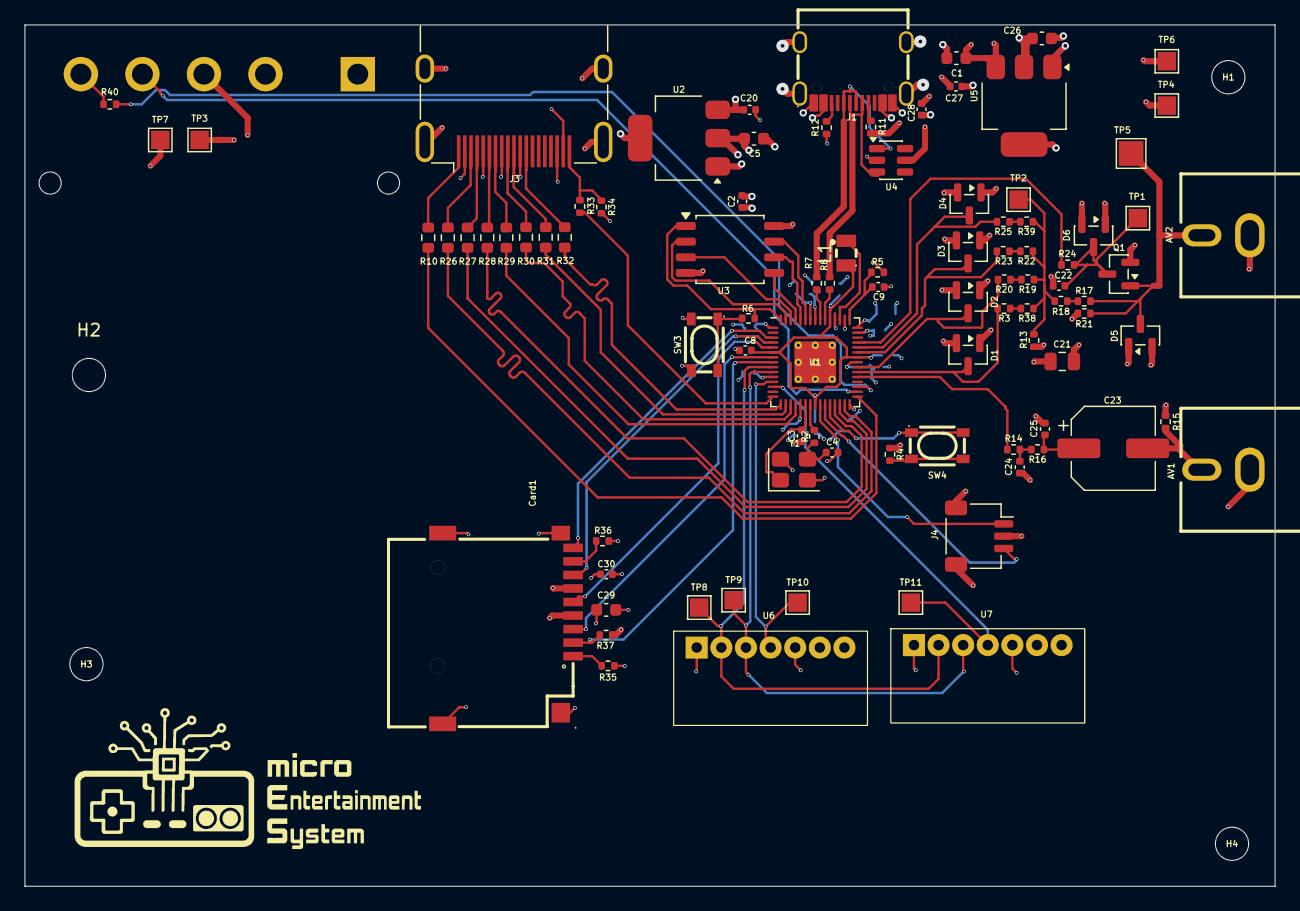
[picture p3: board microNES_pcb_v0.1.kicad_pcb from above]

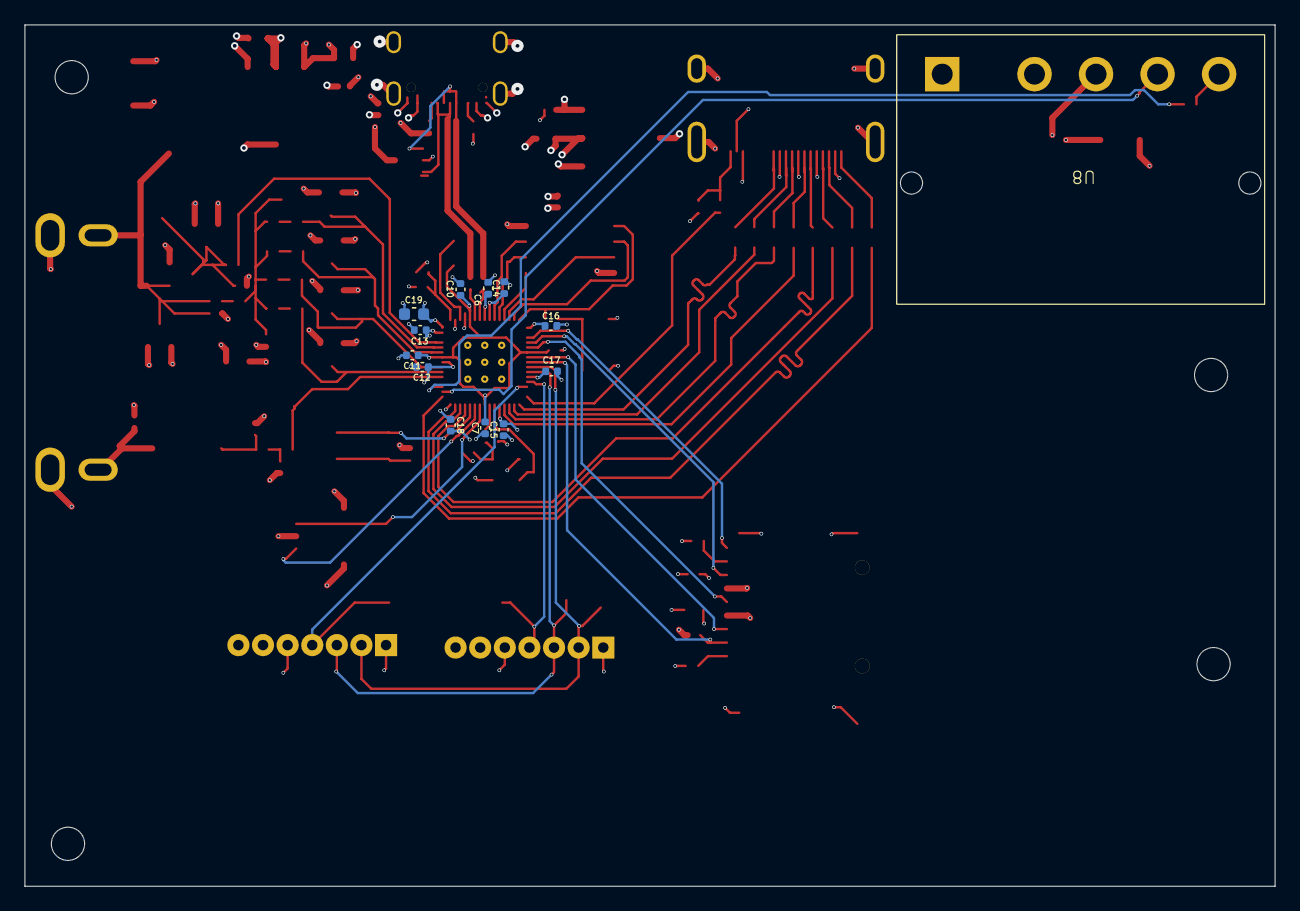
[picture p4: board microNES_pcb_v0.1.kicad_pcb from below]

Board: 4 copper layers, 101.6 x 70.0 mm, 108 parts (13 on the bottom side), 77 nets.

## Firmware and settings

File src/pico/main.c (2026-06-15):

#include "app_shell.h"
#include "clock_config.h"
#include "emulator_video_adapter.h"
#include "frame_pacer.h"
#include "hardware/clocks.h"
#include "hardware/vreg.h"
#include "pico_audio_backend.h"
#include "pico_time.h"
#include "pico_video_backend.h"
#include "pico_input.h"
#include "pico_status.h"
#include "rom_source_flash_fs.h"
#include "rom_source.h"
#include "rom_source_sd.h"
#include "save_state_store_sd.h"
#if defined(MICRONES_PICO_VIDEO_BACKEND_TFT)
#include "display/video_tft.h"
#endif

#include "pico/stdlib.h"

#include <stdio.h>

#if MICRONES_PICO_ENABLE_FLASH_ROM_CACHE
#include "rom_menu.h"
typedef struct {
    PicoEmulatorVideoAdapter *adapter;
    NesFrameBuffer *fb;
    bool video_suspended;
} FlashProgressCtx;

static void flash_progress_cb(size_t done, size_t total, void *user) {
    FlashProgressCtx *ctx = (FlashProgressCtx *)user;
    if (ctx->video_suspended) return;
    int pct = (total > 0) ? (int)((done * 100u) / total) : 0;
    rom_menu_render_loading(ctx->fb, "SD -> Flash", pct);
    emulator_video_adapter_present_framebuffer(ctx->adapter, ctx->fb);
}

static void flash_pre_flash_cb(void *user) {
    FlashProgressCtx *ctx = (FlashProgressCtx *)user;
    rom_menu_render_loading(ctx->fb, "This may take 2-3 min", 0);
    for (int i = 0; i < 180; ++i) {
        emulator_video_adapter_present_framebuffer(ctx->adapter, ctx->fb);
        sleep_ms(17);
    }
    ctx->video_suspended = true;
}

static FlashProgressCtx *s_progress_ctx_ptr;

static bool import_fn(RomSource *flash_source, RomSource *sd_source, void *user) {
    (void)user;
    bool ok = rom_source_flash_fs_copy_from(flash_source, sd_source);
    if (s_progress_ctx_ptr) s_progress_ctx_ptr->video_suspended = false;
    return ok;
}

static bool erase_fn(RomSource *flash_source, void *user) {
    (void)user;
    return rom_source_flash_fs_erase(flash_source);
}
#endif

int main(void) {
    const uint32_t audio_sample_rate = pico_audio_backend_preferred_sample_rate();
#if defined(MICRONES_PICO_VIDEO_MODE_EMULATOR)
    static PicoEmulatorVideoAdapter emulator_video;
    static AppShell                 shell;
    static RomSource                sd_rom_source;
    static RomSource                rom_source;
    static SaveStateStore           save_store;
    MicronesFramePacer frame_pacer;
#if MICRONES_ENABLE_PERF_LOG
    uint64_t report_started_us = 0;
    uint64_t report_render_us = 0;
    uint64_t report_step_us = 0;
    uint64_t report_cpu_exec_us = 0;
    uint64_t report_ppu_step_us = 0;
    uint64_t report_ppu_render_us = 0;
    uint64_t report_bus_reads = 0;
    uint64_t report_bus_writes = 0;
    uint64_t report_ppu_cycles = 0;
    uint64_t report_c1_convert_us = 0;
    uint64_t report_c1_begin_wait_us = 0;
    uint64_t report_c1_frames = 0;
    uint32_t report_q_stall_count = 0;
    uint64_t report_q_stall_us = 0;
    PicoVideoBackendStats report_video_stats = { 0 };
    /* Exp A/B: audio pipeline shape + sample correctness */
    uint64_t report_samples_drained = 0;
    uint64_t report_samples_dropped = 0;
    uint64_t report_apu_internal_dropped = 0;
    bool     report_saw_nonzero_sample = false;
#if defined(MICRONES_PICO_VIDEO_BACKEND_TFT)
    /* TFT profiling: per-component breakdown inside present_frame */
    uint64_t report_tft_convert_us = 0;
    uint64_t report_tft_diff_us = 0;
    uint64_t report_tft_spi_us = 0;
    uint64_t report_tft_spans = 0;
#endif
#endif /* MICRONES_ENABLE_PERF_LOG */
#endif

    /* System clock — speed controlled by MICRONES_SYS_CLK_MHZ in clock_config.h.
     * Analog PIO is fixed at 'out pins, 5 [10]' (11 cycles); clkdiv scales
     * to the 14.318182 MHz 4FSC sample clock. */
    vreg_set_voltage(MICRONES_VREG);
    sleep_ms(MICRONES_VREG_SETTLE_MS);
    set_sys_clock_pll(MICRONES_PLL_VCO_HZ, MICRONES_PLL_DIV1, MICRONES_PLL_DIV2);

    /* Explicitly re-configure clk_peri to follow the sys PLL at the new frequency.
     *
     * set_sys_clock_pll() only updates configured_freq[clk_sys].  It does NOT
     * update configured_freq[clk_peri], so clock_get_hz(clk_peri) still returns
     * the SDK-init value (125 MHz or 48 MHz depending on RP2350 defaults).
     *
     * SPI baud-rate selection calls clock_get_hz(clk_peri) to compute CPSDVSR/SCR.
     * If that value is wrong, the SPI clock is wildly off from the requested rate —
     * either far too slow (24 MHz from 48 MHz peri) or too fast (157.5 MHz from a
     * stale 125 MHz peri when actual is 315 MHz).  Either way the display runs wrong.
     *
     * Calling clock_configure here:
     *   1. Points the clk_peri aux mux directly at PLL_SYS (same source as clk_sys).
     *   2. Updates the SDK's configured_freq[clk_peri] to the true sys frequency.
     * After this, spi_init() will compute correct divisors.
     *
     * This is safe for the analog target too: analog uses PIO (clk_sys, not clk_peri)
     * and PWM (clk_sys).  No peripheral that the analog path uses is clk_peri-gated. */
    {
        const uint32_t sys_hz = MICRONES_PLL_VCO_HZ / (MICRONES_PLL_DIV1 * MICRONES_PLL_DIV2);
        clock_configure(clk_peri, 0,
                        CLOCKS_CLK_PERI_CTRL_AUXSRC_VALUE_CLKSRC_PLL_SYS,
                        sys_hz, sys_hz);
    }

    stdio_init_all();

    pico_input_init();
    pico_status_init();    /* lights power LED, arms reset-button edge detect */
    if (!pico_video_backend_init()) {
        printf("video backend init failed: %s\n", pico_video_backend_last_error());
        return 1;
    }
    pico_audio_backend_init(audio_sample_rate);

#if defined(MICRONES_PICO_VIDEO_MODE_EMULATOR) && defined(MICRONES_PICO_VIDEO_BACKEND_HDMI)
    /* Bring HDMI up before SD scanning / ROM menu setup so a missing display
     * signal can be diagnosed independently from storage or cartridge load. */
    pico_video_backend_start_emulator();
#endif

#if defined(MICRONES_PICO_VIDEO_MODE_EMULATOR)
    /* Bring up the adapter with no cart loaded — the ROM picker (AppShell)
     * will load cartridges on demand from the SD card. */
    if (emulator_video_adapter_init_empty(&emulator_video)) {
        /* Initialize the flash-filesystem-backed ROM source.  The flash
         * FS stores ROMs permanently in the 12 MB flash region after
         * firmware.  If no ROMs are in flash yet, the shell enters
         * import mode and lets the user copy from SD card. */
#if MICRONES_PICO_ENABLE_FLASH_ROM_CACHE
        if (!rom_source_flash_fs_init(&rom_source)) {
            rom_source_make_empty(&rom_source);
        }
#else
        rom_source_make_empty(&rom_source);
#endif

        bool sd_ok = rom_source_sd_init(&sd_rom_source);

        app_shell_init(&shell, &rom_source, &emulator_video.nes);

        if (sd_ok && save_state_store_sd_init(&save_store)) {
            app_shell_set_save_store(&shell, &save_store);
        }

#if MICRONES_PICO_ENABLE_FLASH_ROM_CACHE
        {
            static FlashProgressCtx s_progress_ctx;
            s_progress_ctx.adapter = &emulator_video;
            s_progress_ctx.fb = &shell.menu_fb;
            s_progress_ctx.video_suspended = false;
            s_progress_ctx_ptr = &s_progress_ctx;
            rom_source_flash_fs_set_progress(flash_progress_cb, &s_progress_ctx);
            rom_source_flash_fs_set_pre_flash(flash_pre_flash_cb, &s_progress_ctx);
            app_shell_set_erase(&shell, erase_fn, NULL);
            if (sd_ok) {
                app_shell_set_import(&shell, &sd_rom_source, import_fn, NULL);
            }
        }
#else
        (void)sd_ok;
#endif

#if !defined(MICRONES_PICO_VIDEO_BACKEND_HDMI)
        pico_video_backend_start_emulator();
#endif
        micrones_frame_pacer_init(&frame_pacer, true, micrones_pico_clock_now_ns());

#if MICRONES_ENABLE_PERF_LOG
        report_started_us = time_us_64();
#endif

        bool reset_button_was_down = pico_status_reset_button_down();

        while (true) {
            /* Pace emulation to the NTSC NES frame cadence (~16.639 ms,
             * 60.10 Hz) so wall-clock audio production stays aligned with the
             * 48 kHz backend. On the TFT path, capture the next frame
             * deadline so the skip-present logic can decide whether the
             * current frame used too much of the available budget. */
#if defined(MICRONES_PICO_VIDEO_BACKEND_TFT)
            uint64_t frame_deadline_us;
#endif
            {
                uint64_t wait_until_ns = 0u;
                uint64_t now_ns = micrones_pico_clock_now_ns();

                if (micrones_frame_pacer_should_wait(&frame_pacer, now_ns, &wait_until_ns)) {
                    micrones_pico_sleep_until_ns(wait_until_ns);
                    micrones_frame_pacer_note_wait_complete(
                        &frame_pacer,
                        micrones_pico_clock_now_ns());
                }
#if defined(MICRONES_PICO_VIDEO_BACKEND_TFT)
                frame_deadline_us = (frame_pacer.next_deadline_ns + 999ull) / 1000ull;
#endif
            }

            /* Drive the AppShell state machine (menu vs. running).  When in
             * MENU the shell renders into its own framebuffer and we just
             * present that — no NES step, no audio.  When in RUNNING the
             * shell forwards (and combo-masks) the input and we run the
             * normal step+present path below.
             *
             * Player 1 drives the shell (menu navigation, exit combo).
             * Player 2 bypasses the shell and is wired directly to NES
             * controller port 2 — its state should not affect menu
             * navigation, but games that support two players (e.g. SMB1's
             * Luigi mode) will see it on $4017. */
            PicoControllerPair input_pair = pico_input_read_pair();

            /* Front-panel reset button (v0.1 PCB).  Turn the power LED off
             * while the button is held, then restore it and reset the current
             * game on release.  In the menu the reset request is a no-op, but
             * the LED still gives button feedback. */
            bool reset_button_down = pico_status_reset_button_down();
            if (reset_button_down) {
                pico_status_set_led(false);
            } else if (reset_button_was_down) {
                pico_status_set_led(true);
                app_shell_request_reset(&shell);
            }
            reset_button_was_down = reset_button_down;

            AppShellFrame frame = app_shell_begin_frame(&shell, input_pair.players[0]);

            if (frame.just_entered_run) {
                micrones_frame_pacer_init(&frame_pacer, true, micrones_pico_clock_now_ns());
            }

            if (!frame.stepping_nes) {
                emulator_video_adapter_present_framebuffer(
                    &emulator_video, app_shell_menu_framebuffer(&shell));
                micrones_frame_pacer_frame_done(&frame_pacer,
                                                micrones_pico_clock_now_ns());
                continue;
            }
            nes_set_controller_state(&emulator_video.nes, 0, frame.forwarded);
            nes_set_controller_state(&emulator_video.nes, 1, input_pair.players[1]);

#if defined(MICRONES_PICO_VIDEO_BACKEND_TFT)
            /* TFT path: step and present are separated so audio is pushed
             * between them.  This ensures audio is refilled on every NES
             * frame regardless of how long the display present takes. */
            if (!emulator_video_adapter_step_frame(&emulator_video)) {
                printf("emulator video failed: %s\n", emulator_video_adapter_last_error(&emulator_video));
                break;
            }

            /* Drain APU PCM samples into the audio backend immediately after
             * the NES step, before the display present. */
            {
                static int16_t pcm_tmp[256];
                size_t n;
                while ((n = nes_audio_read_samples(&emulator_video.nes, pcm_tmp,
                                                   sizeof(pcm_tmp) / sizeof(pcm_tmp[0]))) > 0) {
#if MICRONES_ENABLE_PERF_LOG
                    size_t pushed = pico_audio_backend_push_samples(pcm_tmp, n);
                    report_samples_drained += n;
                    report_samples_dropped += (n - pushed);
                    if (!report_saw_nonzero_sample) {
                        for (size_t i = 0; i < n; ++i) {
                            if (pcm_tmp[i] != 0) {
                                report_saw_nonzero_sample = true;
                                break;
                            }
                        }
                    }
#else
                    pico_audio_backend_push_samples(pcm_tmp, n);
#endif
                }
#if MICRONES_ENABLE_PERF_LOG
                report_apu_internal_dropped += emulator_video.nes.apu.dropped_samples;
#endif
            }

            /* Present the frame to the display — but skip if the previous
             * frame already overran the 16.67 ms budget.  Skipping one
             * present lets the loop recover to the next deadline without
             * accumulating drift.  The display drops during heavy scenes but
             * NES emulation and audio remain on the NTSC cadence. */
            {
                static bool s_skip_present = false;
                if (!s_skip_present) {
                    emulator_video_adapter_present_frame(&emulator_video);
                }
                /* Record whether this frame (step + audio + present) overran
                 * so the next iteration can decide whether to skip present. */
                s_skip_present = (time_us_64() > frame_deadline_us);
            }
#elif defined(MICRONES_PICO_VIDEO_BACKEND_HDMI)
            {
                if (!emulator_video_adapter_step_frame(&emulator_video)) {
                    printf("emulator video failed: %s\n", emulator_video_adapter_last_error(&emulator_video));
                    break;
                }

                /* Drain APU PCM samples into the audio backend.
                 * The APU produces about 799 samples per NTSC frame at 48 kHz. */
                {
                    static int16_t pcm_tmp[256];
                    size_t n;
                    while ((n = nes_audio_read_samples(&emulator_video.nes, pcm_tmp,
                                                       sizeof(pcm_tmp) / sizeof(pcm_tmp[0]))) > 0) {
#if MICRONES_ENABLE_PERF_LOG
                        size_t pushed = pico_audio_backend_push_samples(pcm_tmp, n);
                        report_samples_drained += n;
                        report_samples_dropped += (n - pushed);
                        if (!report_saw_nonzero_sample) {
                            for (size_t i = 0; i < n; ++i) {
                                if (pcm_tmp[i] != 0) {
                                    report_saw_nonzero_sample = true;
                                    break;
                                }
                            }
                        }
#else
                        pico_audio_backend_push_samples(pcm_tmp, n);
#endif
                    }
#if MICRONES_ENABLE_PERF_LOG
                    report_apu_internal_dropped += emulator_video.nes.apu.dropped_samples;
#endif
                }

                emulator_video_adapter_present_frame(&emulator_video);
            }
#else
            /* Analog path: render_frame handles step + present together,
             * matching the original loop structure. */
            if (!emulator_video_adapter_render_frame(&emulator_video)) {
                printf("emulator video failed: %s\n", emulator_video_adapter_last_error(&emulator_video));
                break;
            }

            /* Drain APU PCM samples into the audio backend.
             * The APU produces about 799 samples per NTSC frame at 48 kHz. */
            {
                static int16_t pcm_tmp[256];
                size_t n;
                while ((n = nes_audio_read_samples(&emulator_video.nes, pcm_tmp,
                                                   sizeof(pcm_tmp) / sizeof(pcm_tmp[0]))) > 0) {
#if MICRONES_ENABLE_PERF_LOG
                    size_t pushed = pico_audio_backend_push_samples(pcm_tmp, n);
                    report_samples_drained += n;
                    report_samples_dropped += (n - pushed);
                    if (!report_saw_nonzero_sample) {
                        for (size_t i = 0; i < n; ++i) {
                            if (pcm_tmp[i] != 0) {
                                report_saw_nonzero_sample = true;
                                break;
                            }
                        }
                    }
#else
                    pico_audio_backend_push_samples(pcm_tmp, n);
#endif
                }
#if MICRONES_ENABLE_PERF_LOG
                report_apu_internal_dropped += emulator_video.nes.apu.dropped_samples;
#endif
            }
#endif
            micrones_frame_pacer_frame_done(&frame_pacer, micrones_pico_clock_now_ns());
        }
        pico_video_backend_start_test_pattern();
        while (true) {
            tight_loop_contents();
        }
    }

#endif

    pico_video_backend_start_test_pattern();

    /* 440 Hz square-wave test tone via PCM ring buffer. */
    {
        static int16_t s_tone_sample;
        uint32_t tone_phase = 0;
        const uint32_t tone_step = (uint32_t)((440ull << 32) / audio_sample_rate);
        while (true) {
            s_tone_sample = (tone_phase & 0x80000000u) ? 16384 : -16384;
            if (pico_audio_backend_push_samples(&s_tone_sample, 1) == 1) {
                tone_phase += tone_step;
            }
        }
    }
}

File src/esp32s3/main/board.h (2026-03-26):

#pragma once

// ============================================================
// GPIO pin definitions for Waveshare ESP32-S3-Touch-AMOLED-1.91
// Verify against your specific board revision's schematic.
// ============================================================

// --- QSPI Display (SH8601 AMOLED) ---
// Pin assignments from official Waveshare schematic
#define BOARD_LCD_QSPI_CS     6   // QSPI chip select
#define BOARD_LCD_QSPI_SCLK  47   // QSPI clock
#define BOARD_LCD_QSPI_D0    18   // QSPI D0
#define BOARD_LCD_QSPI_D1     7   // QSPI D1
#define BOARD_LCD_QSPI_D2    48   // QSPI D2
#define BOARD_LCD_QSPI_D3     5   // QSPI D3
#define BOARD_LCD_RST        17   // AMOLED reset (active low)
#define BOARD_LCD_TE         16   // Tearing-effect pin (NC by default)

// --- I2C bus (shared by Touch + IMU) ---
#define BOARD_I2C_PORT        0   // I2C peripheral number
#define BOARD_I2C_SDA        40   // GP40 per board pinout
#define BOARD_I2C_SCL        39   // GP39 per board pinout
#define BOARD_I2C_FREQ_HZ   400000

// --- Touch controller (FT3168) ---
#define BOARD_TP_I2C_ADDR  0x38   // 7-bit I2C address
#define BOARD_TP_RST         17   // Shared with AMOLED reset (GPIO17)
#define BOARD_TP_INT         41   // TP interrupt pin

// --- IMU (QMI8658) – same I2C bus, not used by emulator ---
#define BOARD_IMU_I2C_ADDR 0x6B   // AD0 pulled high; use 0x6A if AD0 low

// --- Audio output (MAX98357A I2S amplifier) ---
// Wire MAX98357A:  BCLK→GPIO4, LRC→GPIO2, DIN→GPIO3
//                 VIN→3.3V (or 5V for more volume), GND→GND
//                 SD_MODE→leave unconnected ((L+R)/2 mix, best for mono speaker)
//                 OUT+/OUT- directly to 8-ohm speaker
#define BOARD_AUDIO_I2S_PORT   I2S_NUM_0
#define BOARD_AUDIO_BCLK_PIN   4
#define BOARD_AUDIO_WS_PIN     2
#define BOARD_AUDIO_DOUT_PIN   3

// --- NES hardware controller (original 4021 PISO shift register) ---
// Connect the 7-pin NES controller cable as follows:
//   NES pin 1 (VCC)   → 3.3 V
//   NES pin 2 (CLOCK) → GPIO 11 (output from ESP32-S3)
//   NES pin 3 (LATCH) → GPIO 12 (output from ESP32-S3)
//   NES pin 4 (DATA)  → GPIO 13 (input to ESP32-S3; pull-up enabled in firmware)
//   NES pin 7 (GND)   → GND
// Pins 5 and 6 are not connected on a standard NES controller.
#define BOARD_NES_CTL_CLOCK  11
#define BOARD_NES_CTL_LATCH  12
#define BOARD_NES_CTL_DATA   13

// --- Power / battery ADC ---
#define BOARD_BAT_ADC_CHANNEL  ADC_CHANNEL_0   // GPIO1

// ============================================================
// Display geometry
// ============================================================

// Native portrait resolution
#define BOARD_LCD_NATIVE_W   240
#define BOARD_LCD_NATIVE_H   536

// After 90° CW rotation (landscape) used for NES layout
#define DISPLAY_W            536   // landscape width  = native height
#define DISPLAY_H            240   // landscape height = native width

// NES framebuffer: 256×240, placed in the centre of the landscape display
//   left zone  [  0 .. 139] × [0 .. 239]  – D-pad
//   NES region [140 .. 395] × [0 .. 239]  – emulator output
//   right zone [396 .. 535] × [0 .. 239]  – A/B/Start/Select
#define NES_DISPLAY_X        140
#define NES_DISPLAY_Y          0
#define NES_DISPLAY_W        256   // == NES_FRAME_WIDTH
#define NES_DISPLAY_H        240   // == NES_FRAME_HEIGHT

#define UI_LEFT_X              0
#define UI_LEFT_W            140
#define UI_RIGHT_X           396
#define UI_RIGHT_W           140

// SPI bus configuration
#define BOARD_LCD_SPI_HOST   SPI2_HOST
#define BOARD_LCD_SPI_CLK_HZ (80 * 1000 * 1000)  // 80 MHz – RM67162 QSPI max

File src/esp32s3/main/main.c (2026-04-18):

#include "audio.h"
#include "board.h"
#include "display.h"
#include "nes_hw_controller.h"
#include "ui.h"

// Portable NES core
#include "nes.h"
#include "framebuffer.h"

#include "esp_heap_caps.h"
#include "esp_log.h"
#include "esp_system.h"
#include "esp_timer.h"
#include "freertos/FreeRTOS.h"
#include "freertos/queue.h"
#include "freertos/semphr.h"
#include "freertos/task.h"

#include <stdlib.h>
#include <stdio.h>
#include <string.h>

static const char *TAG = "micrones";

// ─────────────────────────────────────────────────────────────
//  Embedded ROM (injected by CMakeLists.txt via EMBED_FILES)
// ─────────────────────────────────────────────────────────────
#if MICRONES_HAS_ROM
extern const uint8_t micrones_rom_start[] asm(MICRONES_ROM_START_SYMBOL);
extern const uint8_t micrones_rom_end[]   asm(MICRONES_ROM_END_SYMBOL);
#define ROM_START  micrones_rom_start
#define ROM_SIZE   ((size_t)(micrones_rom_end - micrones_rom_start))
#endif

// ─────────────────────────────────────────────────────────────
//  NES state (static – too large for the default stack)
// ─────────────────────────────────────────────────────────────
static Nes s_nes;

enum {
    DISPLAY_FRAME_BUFFER_COUNT = 2,
};

static NesFrameBuffer *s_display_frames[DISPLAY_FRAME_BUFFER_COUNT];
static SemaphoreHandle_t s_display_frame_free[DISPLAY_FRAME_BUFFER_COUNT];
static QueueHandle_t s_display_frame_queue;

// ─────────────────────────────────────────────────────────────
//  Frame timing
// ─────────────────────────────────────────────────────────────
#define TARGET_FRAME_US  16667u   // ~60 fps

static bool display_frames_init(void)
{
    for (unsigned i = 0; i < DISPLAY_FRAME_BUFFER_COUNT; ++i) {
        s_display_frames[i] = (NesFrameBuffer *)heap_caps_malloc(sizeof(NesFrameBuffer),
                                                                 MALLOC_CAP_INTERNAL | MALLOC_CAP_8BIT);
        if (s_display_frames[i] == NULL) {
            s_display_frames[i] = (NesFrameBuffer *)malloc(sizeof(NesFrameBuffer));
        }
        if (s_display_frames[i] == NULL) {
            ESP_LOGE(TAG, "Failed to allocate display frame buffer %u", i);
            return false;
        }
        memset(s_display_frames[i], 0, sizeof(NesFrameBuffer));

        s_display_frame_free[i] = xSemaphoreCreateBinary();
        if (s_display_frame_free[i] == NULL) {
            ESP_LOGE(TAG, "Failed to create display semaphore %u", i);
            return false;
        }
        xSemaphoreGive(s_display_frame_free[i]);
    }

    s_display_frame_queue = xQueueCreate(DISPLAY_FRAME_BUFFER_COUNT, sizeof(uint32_t));
    if (s_display_frame_queue == NULL) {
        ESP_LOGE(TAG, "Failed to create display frame queue");
        return false;
    }

    ESP_LOGI(TAG, "display frame buffers: %u x %u bytes, free internal heap: %lu bytes",
             (unsigned)DISPLAY_FRAME_BUFFER_COUNT,
             (unsigned)sizeof(NesFrameBuffer),
             (unsigned long)heap_caps_get_free_size(MALLOC_CAP_INTERNAL));
    return true;
}

static uint32_t display_acquire_frame_buffer(uint32_t preferred_index)
{
    uint32_t index = preferred_index % DISPLAY_FRAME_BUFFER_COUNT;

    while (true) {
        for (unsigned attempt = 0; attempt < DISPLAY_FRAME_BUFFER_COUNT; ++attempt) {
            uint32_t candidate = (index + attempt) % DISPLAY_FRAME_BUFFER_COUNT;
            if (xSemaphoreTake(s_display_frame_free[candidate], 0) == pdTRUE) {
                return candidate;
            }
        }

        xSemaphoreTake(s_display_frame_free[index], portMAX_DELAY);
        return index;
    }
}

static void display_task(void *arg)
{
    (void)arg;

    while (true) {
        uint32_t frame_index = 0;
        if (xQueueReceive(s_display_frame_queue, &frame_index, portMAX_DELAY) != pdTRUE) {
            continue;
        }

        const NesFrameBuffer *fb = s_display_frames[frame_index];
        display_stream_begin(NES_DISPLAY_X, NES_DISPLAY_Y,
                             NES_DISPLAY_W, NES_DISPLAY_H);
        for (int y = 0; y < NES_FRAME_HEIGHT; ++y) {
            const uint8_t *row = nes_framebuffer_scanline_const(fb, (uint16_t)y);
            display_stream_indexed_row(row, NES_FRAME_WIDTH);
        }
        display_stream_end();

        xSemaphoreGive(s_display_frame_free[frame_index]);
    }
}

typedef struct {
    uint32_t nes_us;
    uint32_t audio_us;
} StepTimes;

#if MICRONES_ENABLE_PERF_LOG
static void print_diag(uint64_t period_us, uint32_t frames,
                       uint32_t audio_pushed, uint32_t audio_skipped, uint32_t audio_overflow,
                       const StepTimes *avg, uint32_t insn_per_frame)
{
    double fps       = (frames * 1000000.0) / (double)period_us;
    double frame_ms  = (double)period_us / (frames * 1000.0);
    ESP_LOGI(TAG,
        "frames=%lu fps=%.1f frame_ms=%.2f | nes=%luus audio=%luus insn/frame=%lu | "
        "audio_pushed=%lu audio_skipped=%lu audio_overflow=%lu audio_free=%u",
        (unsigned long)frames, fps, frame_ms,
        (unsigned long)avg->nes_us,
        (unsigned long)avg->audio_us,
        (unsigned long)insn_per_frame,
        (unsigned long)audio_pushed,
        (unsigned long)audio_skipped,
        (unsigned long)audio_overflow,
        (unsigned)audio_free_slots());
}
#endif
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

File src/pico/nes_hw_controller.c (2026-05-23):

#include "nes_hw_controller.h"
#include "pico_input.h"       // PICO_NES_CTL_* pin definitions

#include "hardware/gpio.h"
#include "hardware/timer.h"   // busy_wait_us_32 – non-sleeping busy-wait

#include <stdio.h>

/* Edge-triggered printf of the raw 8-bit DATA shift-register sample on
 * every change in button state.  Useful for diagnosing "wrong button
 * registers / all buttons register" symptoms by exposing what the
 * 4021 actually puts on the wire.  Output format:
 *   ctl: p1 raw=10110111 buttons=0x40   (Up only -> bit 4 low)
 *        p2 raw=11111111 buttons=0x00
 * Bits in raw[] are in shift order: 0=A 1=B 2=Sel 3=Start 4=Up 5=Dn 6=L 7=R.
 * Build with -DMICRONES_NES_CTL_DEBUG=0 to disable. */
#ifndef MICRONES_NES_CTL_DEBUG
#define MICRONES_NES_CTL_DEBUG 0
#endif

// ── GPIO init ────────────────────────────────────────────────────────────

void nes_hw_controller_init(void)
{
    // CLOCK and LATCH are outputs, idle low.  Default 4 mA drive — the
    // 12 mA bump made things worse on the breadboard (likely overshoot
    // / reflections on long jumpers).
    gpio_init(PICO_NES_CTL_CLOCK);
    gpio_set_dir(PICO_NES_CTL_CLOCK, GPIO_OUT);
    gpio_put(PICO_NES_CTL_CLOCK, 0);

    gpio_init(PICO_NES_CTL_LATCH);
    gpio_set_dir(PICO_NES_CTL_LATCH, GPIO_OUT);
    gpio_put(PICO_NES_CTL_LATCH, 0);

    // DATA is an input with pull-up (guards against floating when no controller
    // is connected – all bits read 1, meaning no button pressed).
    gpio_init(PICO_NES_CTL_DATA);
    gpio_set_dir(PICO_NES_CTL_DATA, GPIO_IN);
    gpio_pull_up(PICO_NES_CTL_DATA);

#ifdef PICO_NES_CTL_DATA_P2
    gpio_init(PICO_NES_CTL_DATA_P2);
    gpio_set_dir(PICO_NES_CTL_DATA_P2, GPIO_IN);
    gpio_pull_up(PICO_NES_CTL_DATA_P2);
#endif
}

// ── Read cycle ───────────────────────────────────────────────────────────

void nes_hw_controller_read_pair(NesControllerState *p1_out,
                                 NesControllerState *p2_out)
{
    // Step 1: latch all eight button states into the 4021 shift register(s).
    // CLOCK and LATCH are shared between both pads on the v0.1 PCB, so a
    // single LATCH pulse captures both controllers simultaneously.
    gpio_put(PICO_NES_CTL_LATCH, 1);
    busy_wait_us_32(NES_HW_CTL_LATCH_US);
    gpio_put(PICO_NES_CTL_LATCH, 0);
    busy_wait_us_32(NES_HW_CTL_CLOCK_US);    // settle before first sample

    // Step 2: shift out 8 bits per port.
    // DATA is active-low: 0 = button pressed, 1 = released.
    static const uint8_t k_map[8] = {
        NES_BUTTON_A,      NES_BUTTON_B,    NES_BUTTON_SELECT, NES_BUTTON_START,
        NES_BUTTON_UP,     NES_BUTTON_DOWN, NES_BUTTON_LEFT,   NES_BUTTON_RIGHT,
    };

    uint8_t buttons_p1 = 0;
    uint8_t buttons_p2 = 0;
#if MICRONES_NES_CTL_DEBUG
    uint8_t raw_p1[8];
    uint8_t raw_p2[8];
#endif
    for (int i = 0; i < 8; ++i) {
        bool bit_p1 = gpio_get(PICO_NES_CTL_DATA);
#ifdef PICO_NES_CTL_DATA_P2
        bool bit_p2 = gpio_get(PICO_NES_CTL_DATA_P2);
#else
        bool bit_p2 = true;  /* no port wired → reads "no buttons" */
#endif
#if MICRONES_NES_CTL_DEBUG
        raw_p1[i] = bit_p1 ? 1u : 0u;
        raw_p2[i] = bit_p2 ? 1u : 0u;
#endif
        if (!bit_p1) {
            buttons_p1 |= k_map[i];
        }
        if (!bit_p2) {
            buttons_p2 |= k_map[i];
        }
        // Rising edge shifts both 4021s to present the next button on DATA.
        gpio_put(PICO_NES_CTL_CLOCK, 1);
        busy_wait_us_32(NES_HW_CTL_CLOCK_US);
        gpio_put(PICO_NES_CTL_CLOCK, 0);
        busy_wait_us_32(NES_HW_CTL_CLOCK_US);
    }

#if MICRONES_NES_CTL_DEBUG
    /* Edge-trigger: only emit a line when either port's state changes, so
     * the USB CDC log isn't flooded at 60 Hz. */
    static uint8_t s_last_p1 = 0;
    static uint8_t s_last_p2 = 0;
    static bool    s_seen = false;
    if (!s_seen || buttons_p1 != s_last_p1 || buttons_p2 != s_last_p2) {
        printf("ctl: p1 raw=%u%u%u%u%u%u%u%u buttons=0x%02X | "
               "p2 raw=%u%u%u%u%u%u%u%u buttons=0x%02X\n",
               raw_p1[0], raw_p1[1], raw_p1[2], raw_p1[3],
               raw_p1[4], raw_p1[5], raw_p1[6], raw_p1[7],
               (unsigned)buttons_p1,
               raw_p2[0], raw_p2[1], raw_p2[2], raw_p2[3],
               raw_p2[4], raw_p2[5], raw_p2[6], raw_p2[7],
               (unsigned)buttons_p2);
        s_last_p1 = buttons_p1;
        s_last_p2 = buttons_p2;
        s_seen = true;
    }
#endif

    if (p1_out) {
        p1_out->buttons = buttons_p1;
    }
    if (p2_out) {
        p2_out->buttons = buttons_p2;
    }
}

NesControllerState nes_hw_controller_read(void)
{
    NesControllerState p1, p2;
    nes_hw_controller_read_pair(&p1, &p2);
    (void)p2;
    return p1;
}

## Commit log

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2026-03-13 audio attempted fixes, not working
    [apu.c]
2026-03-13 fix most audio problems
    [apu.c]
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2026-03-18 make button work correctly
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2026-03-20 Add web frontend (Emscripten/WASM)
    Adds a third frontend alongside the existing host (SDL3) and pico frontends,
    letting the NES core run in a web browser via WebAssembly.
    - src/web/web_main.c: thin Emscripten wrapper exposing nes_web_* entry
    points (init, load_rom, step_frame, framebuffer_ptr, audio, controller,
    reset) via EMSCRIPTEN_KEEPALIVE so they are callable from JavaScript.
    - src/web/index.html: self-contained single-page app that loads
    micrones.js (the Emscripten glue), accepts a .nes file via drag-and-drop
    or file picker, renders to a <canvas> using the same NES palette as the
    SDL host, drives audio via Web Audio API (ScriptProcessorNode + ring
    buffer), and maps keyboa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
2026-03-20 Add GitHub Actions workflow to build WASM and deploy to GitHub Pages
    Installs Emscripten 3.1.73 via setup-emsdk, runs emcmake + cmake --build
    with MICRONES_PLATFORM=web, then uploads build-web/ (micrones.js,
    micrones.wasm, index.html) as a Pages artifact and deploys it.
    Triggers on push to main or the current WASM feature branch, plus
    workflow_dispatch for manual runs.
    One manual step required: in the repo's Settings → Pages, set the
    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
2026-03-20 Fix Pages deployment: push to gh-pages branch instead
    The Actions environment deployment was blocked by branch protection rules
    that restrict github-pages deployments to the default branch only.
    Switch to peaceiris/actions-gh-pages which pushes build-web/ directly to
    the gh-pages branch, bypassing that restriction. In repo Settings -> Pages
    set source to branch=gh-pages, folder=/ (root).
    https://claude.ai/code/session_01Y8gn48uHqw9CXZDcU3KQwv
2026-03-21 Add mobile touch controller for phones/tablets
    Detects touch devices and renders an NES-style controller below the
    emulator canvas. D-pad on the left, B/A red buttons on the right,
    SELECT/START pill buttons in the center, and a menu button for reset.
    Uses pointer events with setPointerCapture for reliable multi-touch.
    Keyboard controls hint is hidden on touch devices via CSS.
    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
2026-03-21 Fix touch controller layout overflow and iOS audio
    Shrink D-pad cells (46→38px), A/B wraps (62→54px), and center buttons
    so everything fits on narrow phone screens without clipping. Switch
    ctrl-face gap to 0 with flex:1 on center section for proportional fill.
    Resume AudioContext on controller touch to fix iOS Safari audio muting.
    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
2026-03-21 more audio fixes but not quite done
    [apu.c]
2026-03-21 another attempted fix that didn't work
    [apu.c]
2026-03-22 Fix three triangle channel artifacts in APU
    1. Reorder triangle timer after frame counter: the sequencer was being
    advanced before length/linear counter updates fired by the frame
    counter, causing extra sequencer steps at note-off boundaries.
    2. Remove timer_period >= 2 gate from sequencer advance: on real NES
    hardware this check only silences the output, it does not freeze the
    sequencer. Freezing caused phase discontinuity clicks when
    transitioning from a sub-minimum period back to a normal pitch.
    3. Tune DC level tracker from 0.76 Hz to ~16 Hz to match the real NES
    analog RC high-pass filter on the output stage. The previous slow
    constant caused a noticeable swell/de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
    [apu.c]
2026-03-22 Fix triangle channel aliasing and phantom note bugs
    1. Raise minimum timer period threshold from 2 to 8 in the output gate.
    Periods 2-7 produce fundamentals near 7-18 kHz whose upper harmonics
    alias back into the audible range at 48 kHz (e.g. period=2 aliases
    the 3rd harmonic to ~7.9 kHz). The real NES analog output stage
    filters these; raising the threshold to 8 matches the reference
    InfoNES implementation and eliminates the aliasing artifact.
    2. Zero the linear counter when the triangle channel is disabled via
    $4015. Previously only the length counter was cleared, allowing the
    channel to resume immediately on re-enable without a new $400B write.
    This matches InfoNE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
    [apu.c]
2026-03-22 Fix triangle channel click on every note
    Reset the triangle sequencer to the zero-crossing position (step 15,
    value=0) when the linear counter reloads from zero. The real 2A03 does
    not reset the sequencer on note start, but without the NES hardware's
    analog output smoothing the waveform phase is arbitrary at note-on,
    causing the output to jump from silence to a mid-waveform amplitude and
    producing an audible click on every note.
    Also revert the DC tracker constant from 0.00209 back to 0.0001. The
    faster constant was the wrong direction: it decays the DC baseline to
    zero between notes, which increases the effective amplitude jump at
    note-on and makes the click louder rather than quieter.
    ht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
    [apu.c]
2026-03-24 Replace APU with InfoNES DDS synthesis engine
    Rewrites apu.h and apu.c to use the InfoNES_pAPU phase-accumulator
    (DDS) approach instead of the original cycle-accurate timer + sequencer
    model.
    Key changes:
    - Waveform synthesis uses a 32-bit phase accumulator (skip/index/table)
    per channel, with InfoNES's pulse_25/50/75/87 and triangle_50 wave
    tables verbatim from InfoNES_pAPU.cpp.
    - Envelope, length counter, and sweep updates fire once per NES video
    frame (~60 Hz) in apu_vsync(), matching InfoNES's pAPUVsync() cadence.
    - Register writes take effect immediately (no event queue).
    - Magic constants are scaled from InfoNES's 44100 Hz values to 48000 Hz.
    - All nes.c hash-state compatibility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
    [apu.c]
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2026-03-24 Fix four web audio issues: underflow click, rate mismatch, dead loop, reset pop
    - ringPop(): exponential fade to silence on underflow instead of hard
    cut to 0, which caused an audible click on any buffer starve
    - setupAudio(): check audioCtx.sampleRate after creation and warn if
    the browser ignored the requested 48 kHz (e.g. Safari at 44.1 kHz)
    - AUDIO_TMP_SAMPLES: reduce 4096 -> 1536 (= APU_PCM_CAPACITY) so the
    drain loop condition can actually fire and flush a full buffer
    - apu_reset(): preserve dc_level_tracker across reset so the first
    post-reset sample isn't subtracted against 0, which caused a pop
    https://claude.ai/code/session_01JGvBCvu8FHk9iCnNE7CjWf
    [apu_micrones.c]
2026-03-24 Add ESP32-S3 AMOLED build target for Waveshare 1.91" board
    Creates src/esp32s3/ as a standalone ESP-IDF project targeting the
    Waveshare ESP32-S3-Touch-AMOLED-1.91 (SH8601, 240×536, QMI8658, FT3168).
    Layout: display rotated 90° CW → landscape 536×240
    - Left 140 px: D-pad (cross shape with directional arrows)
    - Centre 256 px: NES 256×240 output, 1:1 pixel mapping
    - Right 140 px: A/B buttons (large circles) + Start/Select (small, top)
    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
    [partitions.csv]
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2026-03-24 esp32s3: fix audio.c compile errors
    - Add esp_attr.h include for IRAM_ATTR (was undeclared)
    - Switch esp_timer dispatch from ESP_TIMER_ISR to ESP_TIMER_TASK:
    ledc_set_duty/ledc_update_duty are not ISR-safe so task dispatch
    is required; ESP_TIMER_ISR also needs CONFIG_ESP_TIMER_SUPPORTS_ISR_DISPATCH_METHOD
    which is off by default
    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
2026-03-24 esp32s3: remove unused draw_pixel and kLabel from ui.c
    Both were dead code causing -Werror build failures.
    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
2026-03-24 esp32s3: increase emulator task stack to 32 KB
    16 KB was too small for the nes_step_frame call depth with
    MICRONES_ENABLE_FRAMEBUFFER=1, causing a crash loop on boot.
    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
    [main.c]
2026-03-24 esp32s3: add USB CDC startup delay and verbose init logging
    Without a delay, the firmware crashes before USB CDC enumerates and
    all output is lost. A 3-second delay in app_main gives the host time
    to open the serial port. Added step-by-step ESP_LOGI around each
    hardware init call so the monitor output shows exactly where a crash
    originates.
    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
    [main.c]
2026-03-24 esp32s3: disable PSRAM to fix pre-app_main crash loop
    PSRAM init (ets_delay_us in ROM) was panicking before app_main ran,
    causing an infinite reset loop that prevented USB CDC from enumerating.
    All NES buffers fit in the ESP32-S3's 512 KB internal SRAM so PSRAM
    is not required. Re-enable once basic boot is confirmed.
    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
2026-03-24 esp32s3: switch console to USB Serial/JTAG hardware peripheral
    USB CDC (software) caused a boot:0x2 / download-mode loop on macOS:
    opening the serial monitor asserts CDC control signals that pull
    GPIO0 low, forcing the chip into download mode on every reset.
    USB Serial/JTAG is a hardware peripheral in the ESP32-S3 silicon.
    It works from the very first ROM boot message, needs no firmware
    init, and does not interfere with boot strapping pins.
    To apply: rm sdkconfig && idf.py fullclean && idf.py build flash monitor
    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
2026-03-24 esp32s3: fix SPI bus lock errors and touch I2C NACK
    display.c:
    - lcd_pixel_begin() now calls spi_device_acquire_bus() before any
    transaction with SPI_TRANS_CS_KEEP_ACTIVE (ESP-IDF requirement)
    - lcd_pixel_chunk() calls spi_device_release_bus() on the final chunk
    - display_stream_end() releases the bus when called early
    touch.c:
    - Increase post-reset delay from 50 ms to 300 ms; FT3168 needs ~200 ms
    after RST deassert before its I2C interface is ready
    - Switch to i2c_master_transmit_receive() (combined write+read) which
    avoids the two-transaction split that was causing NACKs
    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
2026-03-24 esp32s3: fix display, I2C pins, performance, and boot delay
    - board.h: correct I2C SDA/SCL to GPIO40/39 (from board pinout)
    - display.c: fix QSPI address format cmd<<16 (was cmd<<8); SH8601 expects
    the DCS command byte in addr[23:16], not addr[15:8]
    - display.c: add display_blit_region() for single-transaction DMA transfer
    of a full frame directly from internal SRAM (no intermediate copy)
    - display.c: reduce s_row_buf back to 512 pixels; set max_transfer_sz to
    fit a full NES frame (256×240×2 bytes)
    - main.c: remove 3-second boot delay (USB Serial/JTAG doesn't need it)
    - main.c: convert full NES frame CPU-side then send via display_blit_region()
    in one SPI transaction instead of 240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
    [board.h, main.c]
2026-03-24 esp32s3: fix all GPIO pins from official schematic + fix blit chunking
    board.h – display pins corrected from schematic:
    QSPI_CS: 10→6, SCLK: 12→47, D0: 11→18, D1: 13→7, D2: 7→48, D3: 14→5
    LCD_RST: 9→17, LCD_TE: 6→16
    TP_INT: 3→41, TP_RST: 2→17 (shares AMOLED reset)
    I2C SDA/SCL already correct (40/39 from previous commit)
    display.c – fix display_blit_region to use BLIT_CHUNK_PIXELS=4096 chunks
    (8192 bytes each) sent directly from DRAM without s_row_buf copy.
    Previous single 122KB transaction exceeded the SPI DMA path checked by
    check_trans_valid; CONFIG_COMPILER_OPTIMIZATION_ASSERTIONS_DISABLE=y
    silently swallowed the ESP_ERROR_CHECK so the blit never h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
    [board.h]
2026-03-24 esp32s3: fix RM67162 init sequence and QSPI address format
    - Rename SH8601_* → LCD_* constants; document chip is RM67162
    - Fix QSPI address format: cmd<<16 → cmd<<8 (RM67162 protocol puts DCS
    command in addr[15:8], i.e. 0x002C00 for RAMWR, NOT 0x2C0000)
    This was why the display showed nothing – every command was garbled.
    - Replace SH8601 init sequence with correct RM67162 QSPI sequence:
    SLPOUT(120ms) → COLMOD(0x55) → MADCTL(0x60) → WRDISBV(0x00) →
    DISPON(120ms) → WRDISBV(0xD0)
    Removed: SWRESET, INVON, NORON (not part of RM67162 QSPI init)
    - Remove TP_RST (GPIO17) toggle – GPIO17 is the shared AMOLED reset line.
    Toggling it in touch_init() wa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
2026-03-24 esp32s3: IRAM hot funcs, -O3, 80 MHz SPI, one-shot blit, INT touch
    Performance: targeting 3.5× speedup (18 fps → 60 fps)
    1. IRAM for NES hot functions (biggest win)
    - runtime_config.h: add ESP32 case for MICRONES_HOT_FUNC that places
    cpu6502_step, ppu_render_scanline, ppu_step_cycles, apu_step and friends
    in .iram1.text instead of flash-backed ICache. The 6502 opcode switch
    table thrashes the 16 KB ICache; running from IRAM eliminates stalls.
    - CMakeLists: add MICRONES_ESP32_PLATFORM=1 define to activate it.
    2. -O3 per-component compile flag
    - CMakeLists: target_compile_options -O3 (override sdkconfig -O2) for all
    sources in this component – tightens the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
    [board.h, main.c]
2026-03-24 esp32s3: fix IRAM literal pool (Xtensa L32R range) + USB CDC delay
    IRAM literal pool fix (critical correctness bug):
    Xtensa LX7 L32R has a ±256 KB PC-relative range. Without
    -mtext-section-literals, the compiler emits literal pools into a
    separate .literal section which the ESP-IDF linker script maps to
    flash (~0x42000000). Our IRAM functions sit at ~0x40374000 – a 28 MB
    gap – so every L32R that references a constant in flash silently loads
    from the wrong address. The large cpu6502_step switch table makes this
    happen immediately, causing a crash-reset loop: device reboots fast
    enough that the USB CDC never establishes and no logs appear, yet the
    display still shows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
    [main.c]
2026-03-24 Enable PSRAM and redesign touch controller UI
    PSRAM fix (sdkconfig.defaults):
    - Enable CONFIG_SPIRAM=y for ESP32-S3R8's 8MB embedded octal PSRAM
    - Use CONFIG_SPIRAM_USE_MALLOC=y so heap overflows to PSRAM automatically
    - Keep allocations <= 16KB in fast internal DRAM
    - Fixes "failed to allocate CHR row cache" – the 41KB ROM copy + 32KB
    CHR cache exhausted internal SRAM alongside the 120KB DMA frame buffer
    UI redesign (ui.c):
    - D-pad: per-pixel bevelled cross with top/left highlights and
    bottom/right shadows for a 3D raised effect; small centre hub;
    filled triangle arrow indicators in each arm
    - A/B buttons: large round red buttons with dome highlight (bright
    top-left spot), 2-px b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
2026-03-24 Fix ROM load OOM via zero-copy flash path; revert PSRAM
    Adds cart_load_ines_const_memory / nes_load_cartridge_const_memory:
    - Points prg_rom and chr_data directly into the caller's buffer
    (the flash-mapped embedded ROM) instead of malloc-copying it
    - Saves ~41 KB of internal SRAM heap, leaving room for the 32 KB
    CHR row cache without needing PSRAM
    - cart_unload is unaffected: rom_image is set to NULL after parse
    so free(NULL) is a no-op; chr_is_ram=false so chr_data is also safe
    main.c now calls nes_load_cartridge_const_memory for the embedded ROM.
    Reverts PSRAM enable in sdkconfig.defaults (keeps CONFIG_SPIRAM=n).
    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
    [main.c]
2026-03-24 Fix blit SPI error and PRG ROM flash performance
    - display_blit_region now uses the streaming API (stream_begin +
    row-by-row stream_row + stream_end) instead of a single large DMA
    transaction. The streaming path is proven working (UI overlay uses it)
    and keeps each SPI transaction at ROW_BUF_PIXELS × 2 = 512 bytes,
    well within the hardware limit. The prior 65536-pixel single-shot
    transaction exceeded max_transfer_sz (122944 bytes), causing the SPI
    driver to reject it with 'txdata transfer > hardware max' and leaving
    the display blank.
    - ROW_BUF_PIXELS reduced from 512 to 256 (one NES scanline = 512 bytes).
    - max_transfer_sz tightened to match.
    cart.c (cart_load_i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
2026-03-24 ESP32-S3 AMOLED performance: 22 FPS → ~56 FPS (#6)
    * Fix AMOLED performance: scanline APU batching + single-shot SPI blit
    Three targeted fixes for the 18 FPS → 60 FPS bottleneck:
    1. nes.c – nes_step_frame now calls nes_step_scanline instead of
    nes_step_instruction. This batches APU flushing to 240×/frame
    (one per scanline) rather than ~9828×/frame (one per instruction),
    saving ~1.8 ms/frame of apu_step call overhead.
    2. display.c – display_blit_region no longer copies each scanline
    through the 512-byte s_row_buf scratch buffer. Instead it sends
    the caller's DMA_ATTR buffer (s_frame_rgb) directly to the SPI
    driver in chunks of up to BLIT_CHUNK_PIXELS (= 256×2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
    [main.c]
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2026-03-26 Fix reset button: rename menu to RESET with NES-style styling
    Move the reset button from the A/B section into the center column,
    centered above SELECT and START. Style it as a gray rectangular
    button with a 3D raised look matching the original NES console Reset
    button aesthetic.
    https://claude.ai/code/session_01UYTpprx3jk8CpmVNhBdGoT
2026-03-26 ci: trigger deploy workflow on fix-reset-button-styling branch
    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
2026-03-26 Move RESET button up without adding extra row
    Reverts ctrl-top row approach (which shifted the gradient stripes) and
    instead uses a negative margin-top on the reset button to lift it into
    the black band above, keeping the controller height unchanged.
    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
2026-03-26 Fix RESET position to not shift SELECT/START buttons
    Use relative positioning + negative margin-bottom instead of
    margin-top, so the button moves up visually without pulling the
    flex siblings along with it.
    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
2026-03-26 Revert reset button position changes, keep initial styling fix
    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
2026-03-26 Replace PWM audio with I2S output via MAX98357A amplifier (#12)
    * Switch ESP32-S3 audio from LEDC PWM to I2S for MAX98357A
    Replaces the PWM buzzer output on GPIO46 with a proper I2S path
    targeting a MAX98357A Class-D amplifier:
    - board.h: new BOARD_AUDIO_I2S_PORT / BCLK_PIN(4) / WS_PIN(2) / DOUT_PIN(3)
    - audio.c: LEDC + timer ISR replaced with i2s_std driver + dedicated
    FreeRTOS task that drains the ring buffer into the I2S DMA FIFO;
    resampling loop removed since I2S runs at the native 48 kHz rate
    - audio.h: update doc comment
    - CMakeLists.txt: add freertos to REQUIRES
    Wiring: MAX98357A BCLK→GPIO4, LRC→GPIO2, DIN→GPIO3,
    VIN→3.3V/5V, OUT+/OUT- directly to 8-ohm speaker.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
    [board.h]
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2026-03-31 4-bit composite color DAC with configurable clock speed (#15)
    * initial 4 bit dac NTSC color implementation
    * update schamtic and pinout
    * add some logging
    * Fix reset button: rename menu to RESET with NES-style styling
    * ci: trigger deploy workflow on fix-reset-button-styling branch
    * Move RESET button to black band above controller face
    Relocates the RESET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
    [clock_config.h, main.c]
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2026-04-11 analog sound fixes (#19)
    [clock_config.h, main.c]
2026-04-15 Fix NTSC composite color accuracy and image scaling (#20)
    * Fix NTSC chroma: increase amplitude to 3.5 and correct 180° phase offset
    The chroma amplitude was 2.5 (±~185mV) causing washed-out colors. Bumped
    to 3.5 (±~280mV) to match NTSC standard saturation levels.
    The chroma LUT phases were not aligned with the 180° colorburst reference,
    shifting all decoded hues by 180°. Added +π to the cosine argument so the
    TV decoder sees each NES hue at its correct angle.
    https://claude.ai/code/session_01U5noarKvnVk15q5vPh9uSZ
    * Revert chroma phase offset, keep amplitude at 3.5
    The +π phase correction made colors worse in practice. Removed it,
    keeping only the amplitude increase from 2.5 to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
2026-04-17 Implement DMC channel and improve audio filtering in APU (#23)
    * Fix triangle click/pop and add minimal DMC channel
    Triangle was gating output to 0 when length/linear counters hit zero,
    producing a hard DC step at note-off (the audible pop). Real hardware
    stops clocking the sequencer but holds the last DAC value; the analog
    HP filters then decay it to 0 over ~30 ms. Drop the silence gate and
    remove the sequence_step=15 note-on hack that compensated for the
    symmetric click.
    Replace the 0.76 Hz leaky DC tracker with a first-order HP filter
    (alpha=0.995, ~38 Hz corner at 48 kHz, ~matches Mesen). This properly
    removes the triangle's held-DC tail and the mixer's DC bias while
    preserving bass co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
    [apu_infones.h, apu_micrones.c, apu_micrones.h]
2026-04-18 disable logging and fix a couple of transperny stuff (#24)
    [main.c]
2026-05-08 initial PCB (#27)
    [microNES_pcb_v0.1-B_Cu.gbr, microNES_pcb_v0.1-B_Mask.gbr, microNES_pcb_v0.1-B_Paste.gbr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]
2026-05-20 MicroNES full PCB! Wire up the v0.1 PCB peripherals (#29)
    * Pico: derive peripheral pin assignments from PCB v0.1 schematic
    Add a canonical board pinout header sourced from
    hardware/microNES_pcb_v0.1/microNES_pcb_v0.1.kicad_sch, and a
    MICRONES_BOARD CMake option (breadboard|v0_1) that drives it into
    every Pico pin header. Default behaviour is unchanged.
    With -DMICRONES_BOARD=v0_1 the firmware now uses the silkscreen
    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
    [microNES_pcb_v0.1.kicad_pcb, microNES_pcb_v0.1.kicad_sch]
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2026-05-22 Fix Pico v0.1 reset button and power LED behavior (#31)
    * fix reset button logic
    * LED and reset fixes
    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
    [main.c]
2026-05-23 Pico SD ROM loading and flash-cache game launch support (#32)
    * make more games work and also update hardware pcb to .v2
    * more fixes to make more games work more reliably
    * update .md file
    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
    [bom.csv, designators.csv, microES_v2_BOM.csv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]
2026-05-24 Fix Pico video signal loss during flash ROM loading (#33)
    * Fix video signal loss during flash ROM loading
    Three root causes addressed:
    1. Flash erase held interrupts disabled for the entire ROM erase (seconds
    for large games). Now erases sector-by-sector so interrupts are only
    blocked for ~50-120ms per sector, preventing timing disruption to
    audio and frame pacing.
    2. HDMI HSTX stop path was missing the RP2350-E5 chained-DMA workaround
    (clear EN bits before aborting). The analog path already had this fix.
    Without it, aborting one chained channel can retrigger its partner,
    leaving DMA half-running and corrupting the HSTX signal on restart.
    3. HDMI resume had no stabiliz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
    [main.c]
2026-05-24 Add flash filesystem for permanent ROM storage (#35)
    * Add flash filesystem for permanent ROM storage from SD card
    Replace the single-ROM flash cache with a multi-ROM flash filesystem that
    stores all .nes files persistently in the 12 MB flash region (4-16 MB).
    When flash is empty, the menu shows an import mode with greyed-out SD card
    entries and a "Copy SD Card to Flash" action. After import, ROMs load
    instantly via XIP with no SD card access needed.
    Flash FS layout: 2-sector directory (8 KB, up to 63 ROMs) followed by
    sector-aligned ROM data. Each entry stores name, offset, size, mapper,
    and iNES metadata.
    https://claude.ai/code/session_01M5y5ekZV6CoEoW4rCa5xtX
    * Fix FlashFsDirEntry pac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
    [main.c]
2026-05-29 Stabilize Pico analog NTSC timing with 2x PPU-dot output (#36)
    * reimplement analog video out - still need color tuning
    * fix hues more - still mario work
    * final hue changes for now
    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
    [clock_config.h, main.c]
2026-05-31 Increase audio PWM carrier resolution from 8-bit to 10-bit (#37)
    * Restore analog PWM audio resolution to 10-bit
    The analog (PWM) path was quantizing every 16-bit APU sample down to
    8 bits via `(raw >> 8) ^ 0x80`, discarding the low byte. This was a side
    effect of the hum fix (d802acf), which split PWM into a free-running
    carrier (wrap=255 -> ~1.23 MHz) plus a 48 kHz sample-rate timer. The
    carrier change alone solved the hum; the drop to 8-bit was unnecessary
    collateral and is what made full emulator audio sound gritty on analog,
    while the digital I2S/host paths (full 16-bit) sound clean.
    Widen the carrier to 10-bit (wrap=1023). At 315 MHz the carrier is
    307.6 kHz, still ~51 dB attenuated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
    [clock_config.h]
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
